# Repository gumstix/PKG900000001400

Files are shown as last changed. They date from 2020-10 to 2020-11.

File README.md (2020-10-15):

# Gumstix Raspberry Pi CM4 Development Board
## PKG900000001400 PKG900000001400

Designed by Gumstix in Geppetto, the **Gumstix Raspberry Pi CM4 Development Board** brings the best of the CM4 to light, from PCIe to Gigabit Ethernet to dual CSI2 cameras.  Whether you're building a NAS server or a face-detecting robot, The CM4 Development board has built-in features that will help your project along.  It provides the following connections for breaking out the features of the Raspberry Pi CM4:

* Raspberry Pi 4 Header
* USB-UART Console Port
* DSI connector for connecting to displays
* 2 x CSI2 connector for connecting a camera
* HDMI port for audio/display
* Gigabit Ethernet port
* USB Type-A port for expandability
* M.2 (M Key) with single lane PCIe, compatible with 2280 NVMe drives and Google Coral

The CM4 Development board is ideal for various applications, Including:
* Network attached mass storage (NAS)
* Media Centers
* Edge AI
* Smart home management

__Links:__
* [AutoDoc Datasheet][autodoc]
* [Specifications][spec]
* [Store Page][store]
* [Schematics and Layout][hardware]

[thumbnail]: https://d3iwea566ns1n1.cloudfront.net/images/product/1ae94bd9fed173c4b6867992084763ec15bd388f.png
[autodoc]: PKG900000001400_AutoDoc.pdf
[spec]: PKG900000001400_SpecSheet.pdf
[store]: https://store.gumstix.com/cm4-development-board/
[hardware]: hardware/hardware.md
[firmware]: firmware/firmware.md

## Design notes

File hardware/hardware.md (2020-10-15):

# Hardware

[Schematic PDF][pdf]
EAGLE [Schematic][sch] and [Layout][brd]

[pdf]: PKG900000001400.pdf
[brd]: PKG900000001400.brd
[sch]: PKG900000001400.sch

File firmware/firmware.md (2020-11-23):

# Firmware

__Custom Gumstix Ubuntu Server 20.04 images for Rasberry Pi CM4__:

* [Ubuntu Server 20.04](https://gumstix-ubuntu.s3-us-west-2.amazonaws.com/2020-10-18/raspberrypi-cm4/rosbuntu_cm4_i2.img.gz)
* Username: ubuntu
* Password: raspberry

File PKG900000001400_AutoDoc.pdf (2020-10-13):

# Gumstix Raspberry Pi CM4 Dev Board

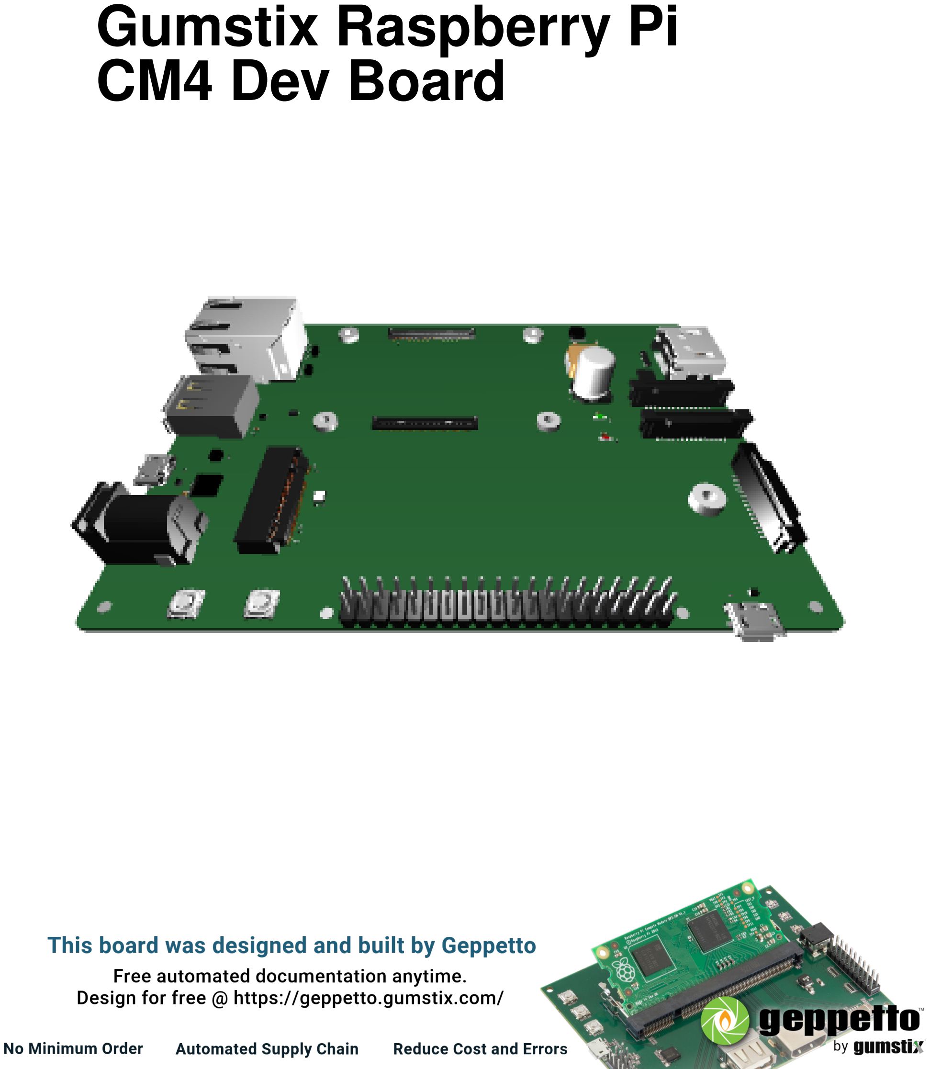
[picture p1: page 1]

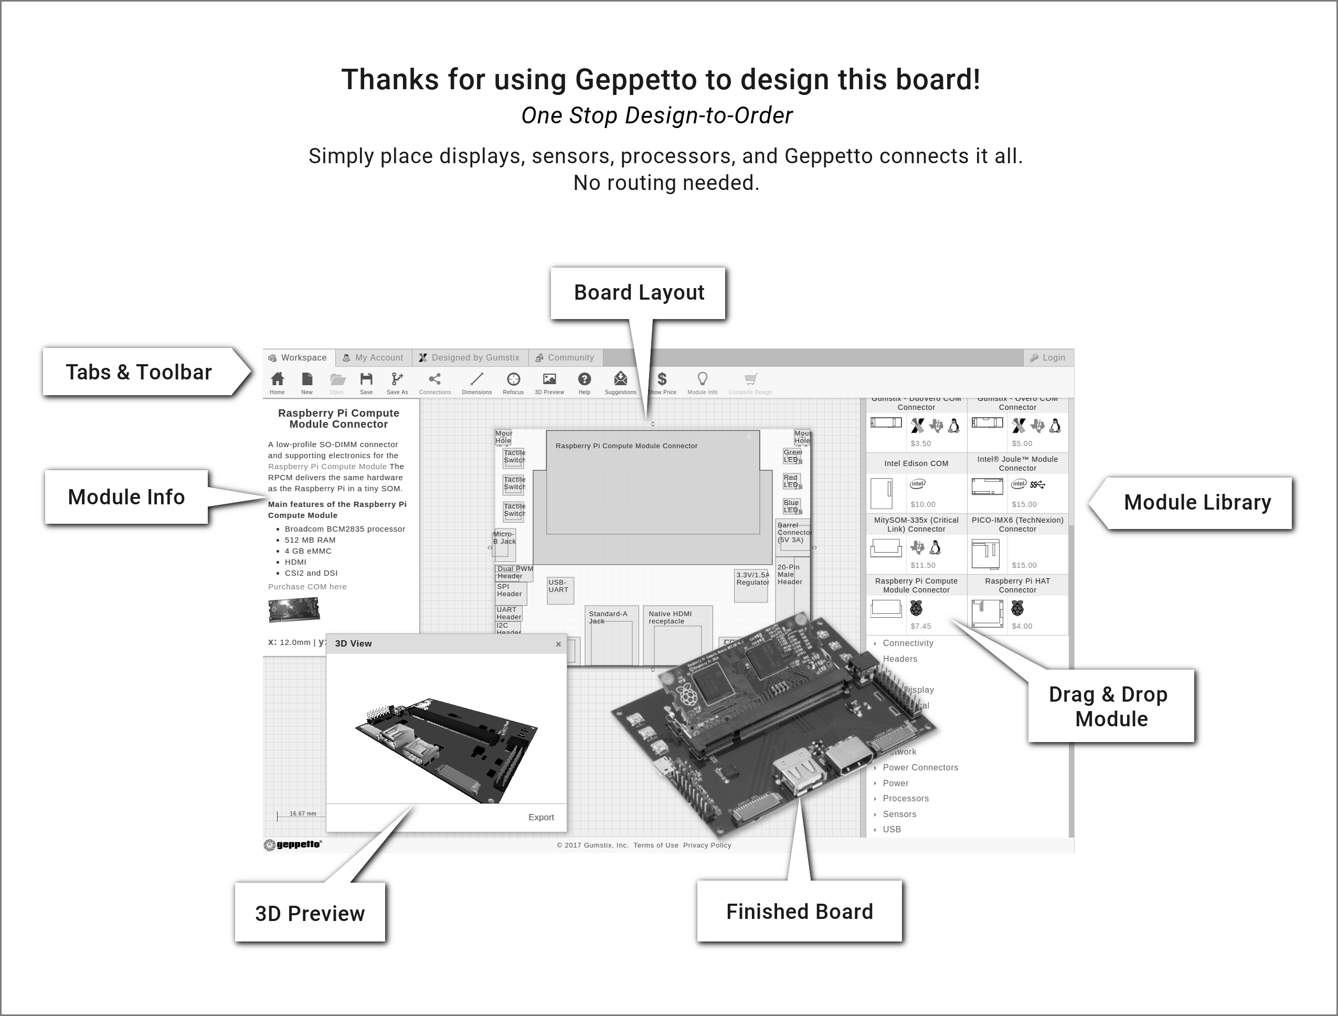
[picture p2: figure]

Gumstix, Inc. shall have no liability of any kind, express or implied, arising out of the use of the Information in this document, including direct, indirect, special or consequential damages.

Gumstix, Inc. may have patents, patent applications, trademarks, copyrights, trade secrets or other intellectual property rights pertaining to Gumstix products described in this document (collectively ”Gumstix Intellectual Property”).

Except as expressly provided in any written license or agreement from Gumstix, Inc., this document and the information contained therein does not create any license to Gumstix’s Intellectual Property.

The Information contained herein is subject to change without notice. Revisions may be issued regarding changes and/or additions.

Copyright

c 2020, Gumstix, Inc. All rights reserved.

## Board Description

Uses Raspberry Pi CM4 as its COM/processor.

Functional modules include:
USB-UART
USB Micro-B Jack
Camera Connector (CSI-2)
M.2 Key M Connector
Ethernet Connector

Powered by a Barrel Connector.

## Board Dimensions

12cm x 8.5cm

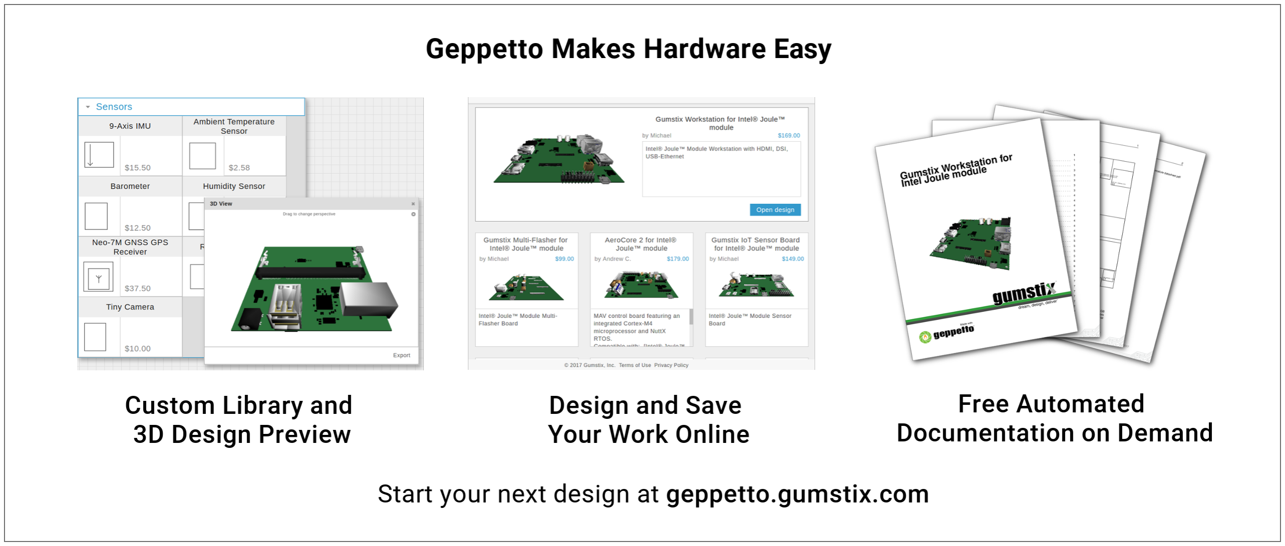
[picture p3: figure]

i

## Contents

1 Modules on Board | 1

ii

Gumstix Raspberry Pi CM4 Dev Board | iii
2 Module Connections Graph | 9
3 Module Power Graph | 10

Revised July 20, 2020

Gumstix Raspberry Pi CM4 Dev Board | 1

## 1 Modules on Board

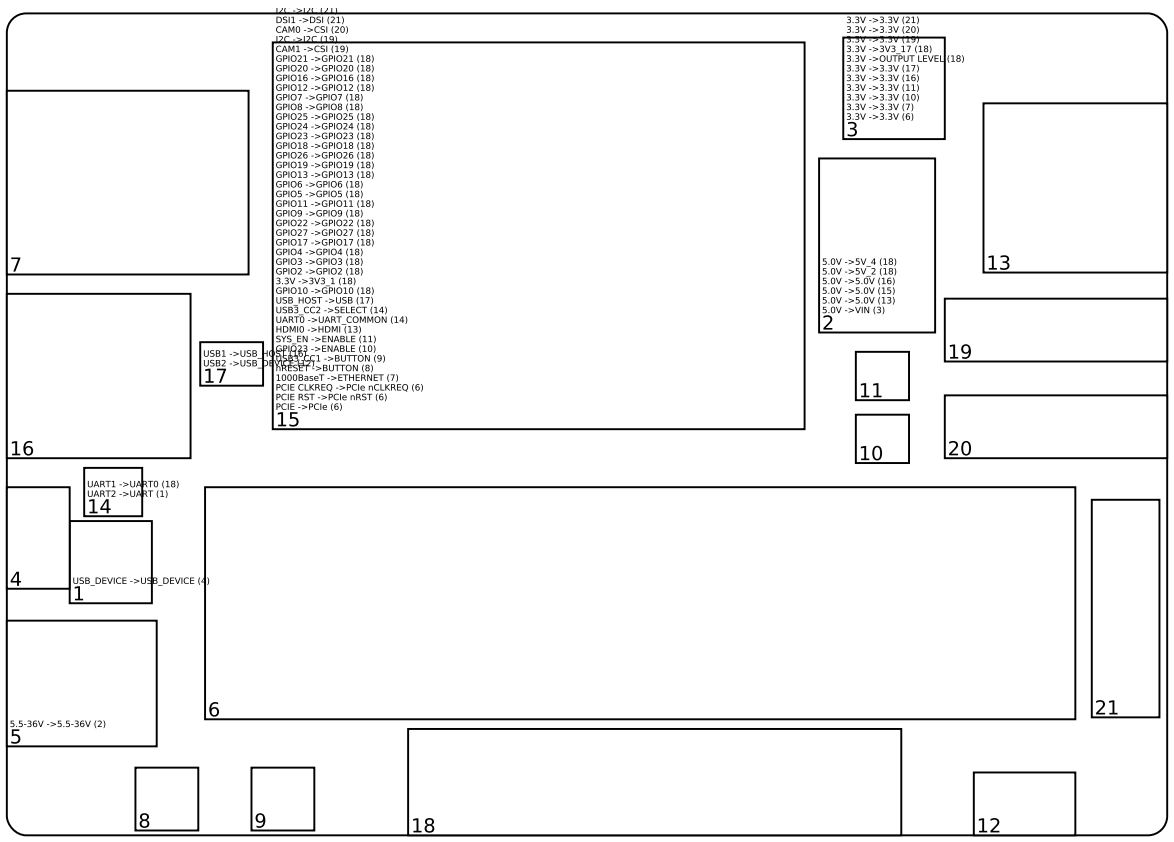
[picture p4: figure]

### 1.1 Converters

### 1.1.1 USB-UART (v21) (1)

Also known as an FTDI, this USB to UART converter allows a USB connection to the board to be-have as a virtual RS232 serial connection. It offers direct and complete access to the system from a development machine by way of the FTDI FT232RQ USB – UART IC.

Technical documentation for the FT232RQ is available at:

http://www.ftdichip.com/Support/Documents/DataSheets/ICs/DS_FT232R.pdf

This USB to UART converter connects a host machine from Micro-B Jack (4) to UART2 on UART Mux (2 output) (14).

### 1.2 Power

1.2.1 5V/5A Regulator (v16) (2)

Takes 5.5 - 36V input from Barrel Connector (2.1mm x 5.5mm) (5) and provides up to 5A at 5V to:

- 3.3V/1.5A Regulator (3)
- HDMI (13)
- Raspberry Pi CM4 Connector (15)
- USB Standard-A Jack (16)
- Raspberry Pi 4 Header (18)
- Raspberry Pi 4 Header (18)

1.2.2 3.3V/1.5A Regulator (v21) (3)

This DC to DC step down regulator provides a 3.3V DC output at 1.5A needed by certain components on this board. It is capable of accepting an input voltage between 3.1 to 16V DC and output is controlled by the TI TPS6211 buck regulator.
It recieves VIN from 5V/5A Regulator (2).

The datasheet for the TPS6211 regulator is available at:

http://www.ti.com/lit/ds/symlink/tps62110.pdf

This regulator provides 3.3V to:

- M.2 Key M Connector (6)
- Ethernet Connector (7)
- Top-side LED (10)
- Top-side LED (11)
- USB Standard-A Jack (16)
- USB 2-Port Switch (17)
- Raspberry Pi 4 Header (18)
- Raspberry Pi 4 Header (18)
- Raspberry Pi Vertical Camera Connector (19)
- Raspberry Pi Vertical Camera Connector (20)
- Raspberry Pi Vertical Display Connector (21)

### 1.3 USB

### 1.3.1 Micro-B Jack (v20) (4)

The USB micro-B port module allows your design to connect as a USB device to a USB host.

This module is connected to USB DEVICE on USB-UART (1).

This module does not supply power.

### 1.3.2 Micro-B Jack (v20) (12)

The USB micro-B port module allows your design to connect as a USB device to a USB host.

This module is connected to USB2 on USB 2-Port Switch (17).

This module does not supply power.

### 1.3.3 USB Standard-A Jack (v19) (16)

A standard A USB host port that allows you to connect USB devices to the board. This port is connected to USB1 on USB 2-Port Switch (17).

### 1.3.4 USB 2-Port Switch (v1) (17)

USB 2-Port Switch allows the sharing of a single USB 2.0 port.

It requires:

- 3.3V from 3.3V/1.5A Regulator (3)
- USB from Raspberry Pi CM4 Connector (15)

It provides the following outputs:

- USB2 to Micro-B Jack (12)
- USB1 to USB Standard-A Jack (16)

### 1.4 Power Connectors

### 1.4.1 Barrel Connector (2.1mm x 5.5mm) (v8) (5)

Standard 2.1mm x 5.1mm barrel connector.

This power jack provides up to 36V to the following modules:

- 5V/5A Regulator (2)

### 1.5 Connectors (Signal)

### 1.5.1 M.2 Key M Connector (v7) (6)

The M.2 Key M expansion slot includes interface options for PCIe (x1, X2, or X4) for SSD’s.

The M.2 Key M Connector module receives the following inputs:

- 3.3V from 3.3V/1.5A Regulator (3)
- PCIe from Raspberry Pi CM4 Connector (15)

- PCIe nRST from Raspberry Pi CM4 Connector (15)
- PCIe nCLKREQ from Raspberry Pi CM4 Connector (15)

### 1.5.2 UART Mux (2 output) (v10) (14)

A bidirectional 2 x SPDT switch connects two UART interfaces (RX/TX only). A SELECT line is used to control which UART is output.

This UART 2-output mux switches between UART0 on Raspberry Pi 4 Header (18) or UART on USB-UART (1) to UART0 on Raspberry Pi CM4 Connector (15).

The output is controlled by USB3 CC2 on Raspberry Pi CM4 Connector (15).

### 1.5.3 Raspberry Pi Vertical Camera Connector (v6) (19) — CAM1

The Raspberry Pi Vertical camera connector module is a 15-pin ribbon connector that exposes a 2-lane MIPI camera system to an external high-resolution camera module.

The CSI port is connected to CAM1 on Raspberry Pi CM4 Connector (15).

I2C communication is connected to I2C on Raspberry Pi CM4 Connector (15).

ENABLE input provided by GPIO CAMERA on Raspberry Pi CM4 Connector (15).

### 1.5.4 Raspberry Pi Vertical Camera Connector (v6) (20) — CAM0

The Raspberry Pi Vertical camera connector module is a 15-pin ribbon connector that exposes a 2-lane MIPI camera system to an external high-resolution camera module.

The CSI port is connected to CAM0 on Raspberry Pi CM4 Connector (15).

I2C communication is connected to I2C ID on Raspberry Pi CM4 Connector (15).

ENABLE input provided by GPIO CAMERA on Raspberry Pi CM4 Connector (15).

### 1.5.5 Raspberry Pi Vertical Display Connector (v1) (21)

The DSI connector module is a 15-pin ribbon connector that exposes a 2-lane MIPI DSI display bus to an external LCD display.

The DSI port is connected to DSI1 on Raspberry Pi CM4 Connector (15)

I2C communication is connected to I2C on Raspberry Pi CM4 Connector (15) .

### 1.6 Network and Wireless

### 1.6.1 Ethernet Connector (v5) (7)

This module offers a 10/100 Base-T or 1000 Base-T Ethernet connection.

The module provides ethernet to

1000BaseT on Raspberry Pi CM4 Connector (15)

### 1.7 Lights and Switches

### 1.7.1 Tactile Switch (v22) (8)

This 4.9 sq. mm pull-down touch switch provides a user input for the signal nRESET on Raspberry Pi CM4 Connector (15).

### 1.7.2 Tactile Switch (v22) (9)

This 4.9 sq. mm pull-down touch switch provides a user input for the signal USB3 CC1 on Raspberry Pi CM4 Connector (15).

### 1.7.3 Top-side LED (v12) (10)

The top-side LED module contains a 1608 standard size LED of a user-selected color, mounted on the top side of a Geppetto board.

The LED is active-high on GPIO23 from Raspberry Pi CM4 Connector (15).

### 1.7.4 Top-side LED (v12) (11)

The top-side LED module contains a 1608 standard size LED of a user-selected color, mounted on the top side of a Geppetto board.

The LED is active-high on SYS EN from Raspberry Pi CM4 Connector (15).

### 1.8 Monitors

### 1.8.1 HDMI (v22) (13)

The native HDMI receptacle module provides HDMI video and audio signals to an external display and speakers. This module uses the TI TPD12S016UFQN HDMI companion chip with a standard HDMI port to provide ESD-protected display connectivity.

The datasheet for the TPD12S016 IC can be found at:

http://www.ti.com/lit/ds/symlink/tpd12s016.pdf

The module transmits high definition video from HDMI0 on Raspberry Pi CM4 Connector (15) .

### 1.9 COM Connectors

### 1.9.1 Raspberry Pi CM4 Connector (v2) (15)

The Raspberry Pi Compute Module 4 (RPCM4) module contains two connectors to interface with the RPCM4 device. The RPCM4 COM connector is ONLY compatible with the RPCM4.

Technical details for the RPCM modules can be found at:

https://www.raspberrypi.org/documentation/hardware/computemodule/datasheet.md

It requires:

- 5.0V from 5V/5A Regulator (2)

The Geppetto Pi Compute 4 connector provides the following outputs:

- PCIE to M.2 Key M Connector (6)
- PCIE RST to M.2 Key M Connector (6)
- PCIE CLKREQ to M.2 Key M Connector (6)
- 1000BaseT to Ethernet Connector (7)
- nRESET to Tactile Switch (8)
- USB3 CC1 to Tactile Switch (9)
- GPIO23 to:

– Top-side LED (10)
– Raspberry Pi 4 Header (18)
- SYS EN to Top-side LED (11)
- HDMI0 to HDMI (13)
- UART0 to UART Mux (2 output) (14)
- USB3 CC2 to UART Mux (2 output) (14)
- USB HOST to USB 2-Port Switch (17)
- GPIO10 to Raspberry Pi 4 Header (18)
- 3.3V to Raspberry Pi 4 Header (18)
- GPIO2 to Raspberry Pi 4 Header (18)
- GPIO3 to Raspberry Pi 4 Header (18)
- GPIO4 to Raspberry Pi 4 Header (18)
- GPIO17 to Raspberry Pi 4 Header (18)
- GPIO27 to Raspberry Pi 4 Header (18)
- GPIO22 to Raspberry Pi 4 Header (18)
- GPIO9 to Raspberry Pi 4 Header (18)

- GPIO11 to Raspberry Pi 4 Header (18)
- GPIO5 to Raspberry Pi 4 Header (18)
- GPIO6 to Raspberry Pi 4 Header (18)
- GPIO13 to Raspberry Pi 4 Header (18)
- GPIO19 to Raspberry Pi 4 Header (18)
- GPIO26 to Raspberry Pi 4 Header (18)
- GPIO18 to Raspberry Pi 4 Header (18)
- GPIO24 to Raspberry Pi 4 Header (18)
- GPIO25 to Raspberry Pi 4 Header (18)
- GPIO8 to Raspberry Pi 4 Header (18)
- GPIO7 to Raspberry Pi 4 Header (18)
- GPIO12 to Raspberry Pi 4 Header (18)
- GPIO16 to Raspberry Pi 4 Header (18)
- GPIO20 to Raspberry Pi 4 Header (18)
- GPIO21 to Raspberry Pi 4 Header (18)
- CAM1 to Raspberry Pi Vertical Camera Connector (19)
- I2C to:

– Raspberry Pi Vertical Camera Connector (19)

– Raspberry Pi Vertical Display Connector (21)

- CAM0 to Raspberry Pi Vertical Camera Connector (20)
- DSI1 to Raspberry Pi Vertical Display Connector (21)
- GPIO CAMERA to:

– Raspberry Pi Vertical Camera Connector (20)

– Raspberry Pi Vertical Camera Connector (19)

- I2C ID to Raspberry Pi Vertical Camera Connector (20)

### 1.10 Custom Modules

### 1.10.1 Raspberry Pi 4 Header (v5) (18)

The 40-pin header module offers up to 40 pins that can be used at the customer’s discretion.

This module has the following connections:

- 5V 2 to 5.0V from 5V/5A Regulator (2)
- 5V 4 to 5.0V from 5V/5A Regulator (2)

- OUTPUT LEVEL to 3.3V from 3.3V/1.5A Regulator (3)
- 3V3 17 to 3.3V from 3.3V/1.5A Regulator (3)
- UART0 to UART1 from UART Mux (2 output) (14)
- GPIO10 to GPIO10 from Raspberry Pi CM4 Connector (15)
- 3V3 1 to 3.3V from Raspberry Pi CM4 Connector (15)
- GPIO2 to GPIO2 from Raspberry Pi CM4 Connector (15)
- GPIO3 to GPIO3 from Raspberry Pi CM4 Connector (15)
- GPIO4 to GPIO4 from Raspberry Pi CM4 Connector (15)
- GPIO17 to GPIO17 from Raspberry Pi CM4 Connector (15)
- GPIO27 to GPIO27 from Raspberry Pi CM4 Connector (15)
- GPIO22 to GPIO22 from Raspberry Pi CM4 Connector (15)
- GPIO9 to GPIO9 from Raspberry Pi CM4 Connector (15)
- GPIO11 to GPIO11 from Raspberry Pi CM4 Connector (15)
- GPIO5 to GPIO5 from Raspberry Pi CM4 Connector (15)
- GPIO6 to GPIO6 from Raspberry Pi CM4 Connector (15)
- GPIO13 to GPIO13 from Raspberry Pi CM4 Connector (15)
- GPIO19 to GPIO19 from Raspberry Pi CM4 Connector (15)
- GPIO26 to GPIO26 from Raspberry Pi CM4 Connector (15)
- GPIO18 to GPIO18 from Raspberry Pi CM4 Connector (15)
- GPIO23 to GPIO23 from Raspberry Pi CM4 Connector (15)
- GPIO24 to GPIO24 from Raspberry Pi CM4 Connector (15)
- GPIO25 to GPIO25 from Raspberry Pi CM4 Connector (15)
- GPIO8 to GPIO8 from Raspberry Pi CM4 Connector (15)
- GPIO7 to GPIO7 from Raspberry Pi CM4 Connector (15)
- GPIO12 to GPIO12 from Raspberry Pi CM4 Connector (15)
- GPIO16 to GPIO16 from Raspberry Pi CM4 Connector (15)
- GPIO20 to GPIO20 from Raspberry Pi CM4 Connector (15)
- GPIO21 to GPIO21 from Raspberry Pi CM4 Connector (15)

## 2 Module Connections Graph

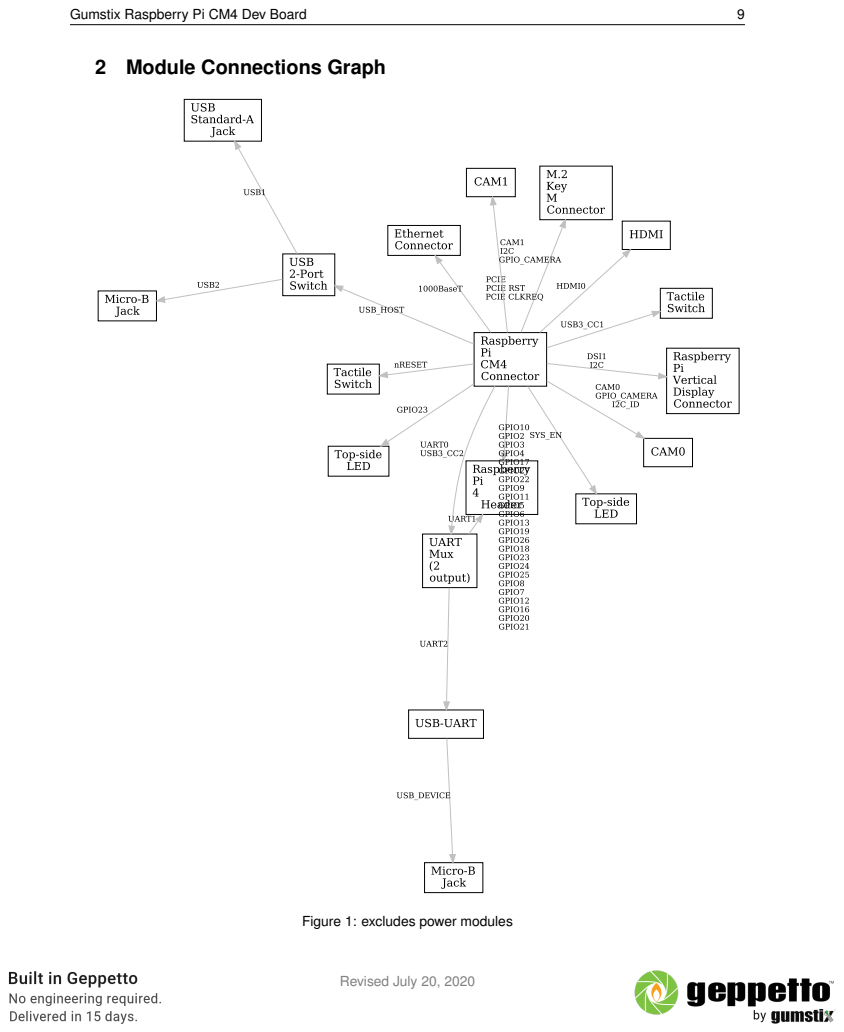
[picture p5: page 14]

Figure 1: excludes power modules

## 3 Module Power Graph

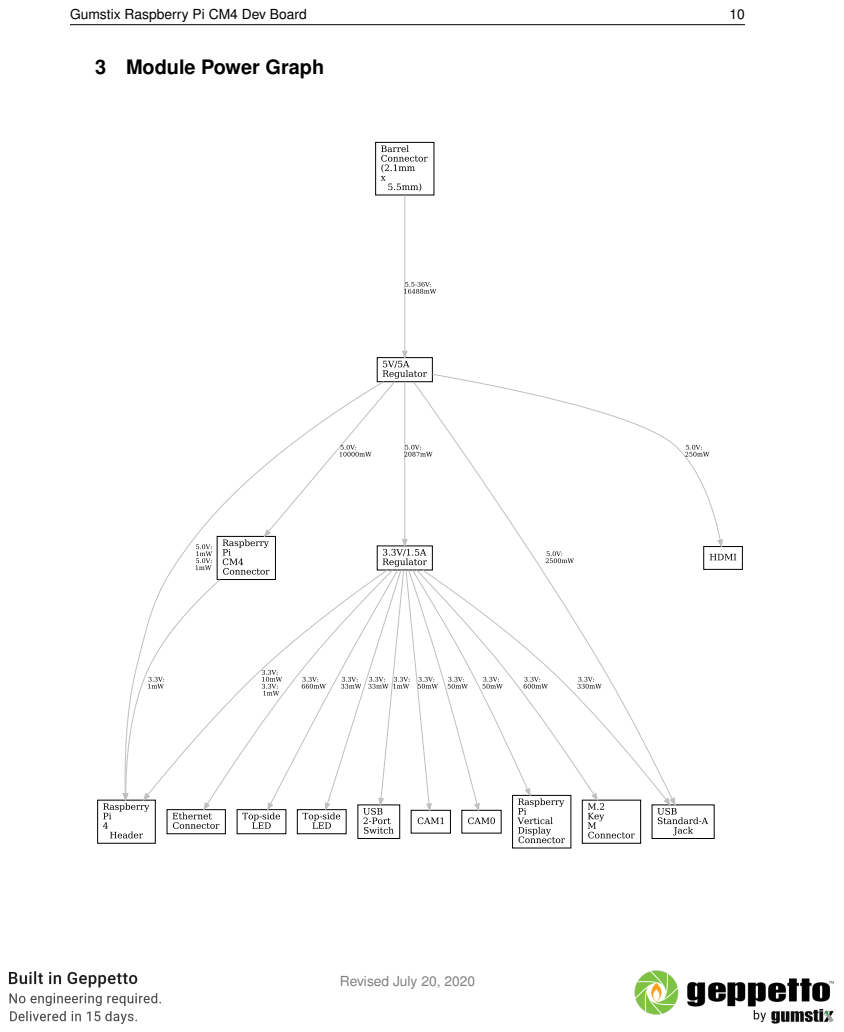
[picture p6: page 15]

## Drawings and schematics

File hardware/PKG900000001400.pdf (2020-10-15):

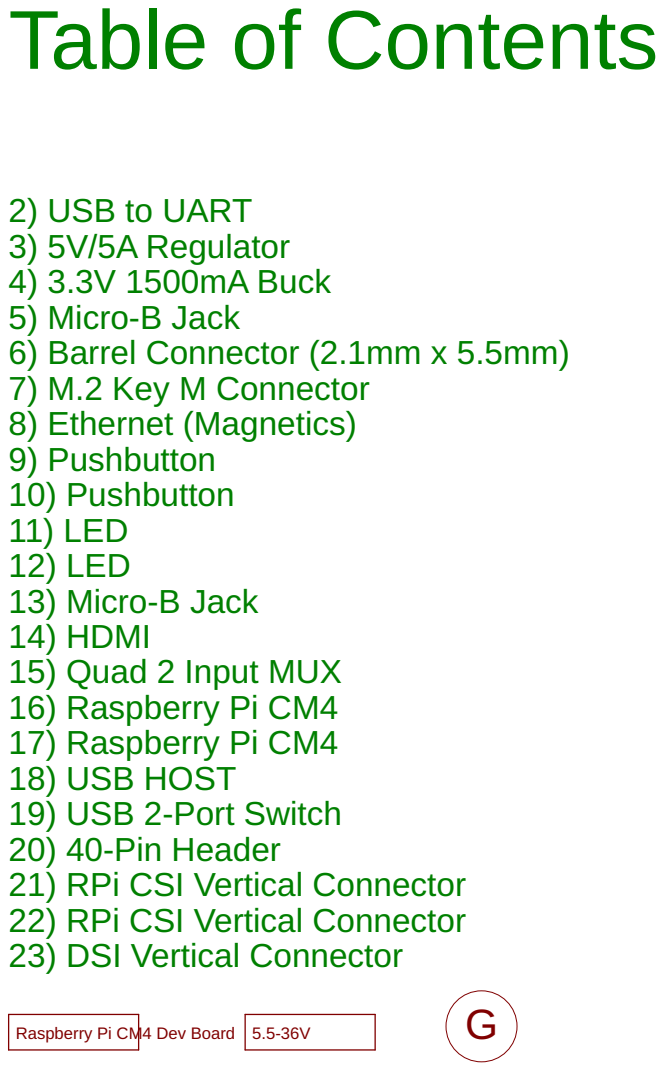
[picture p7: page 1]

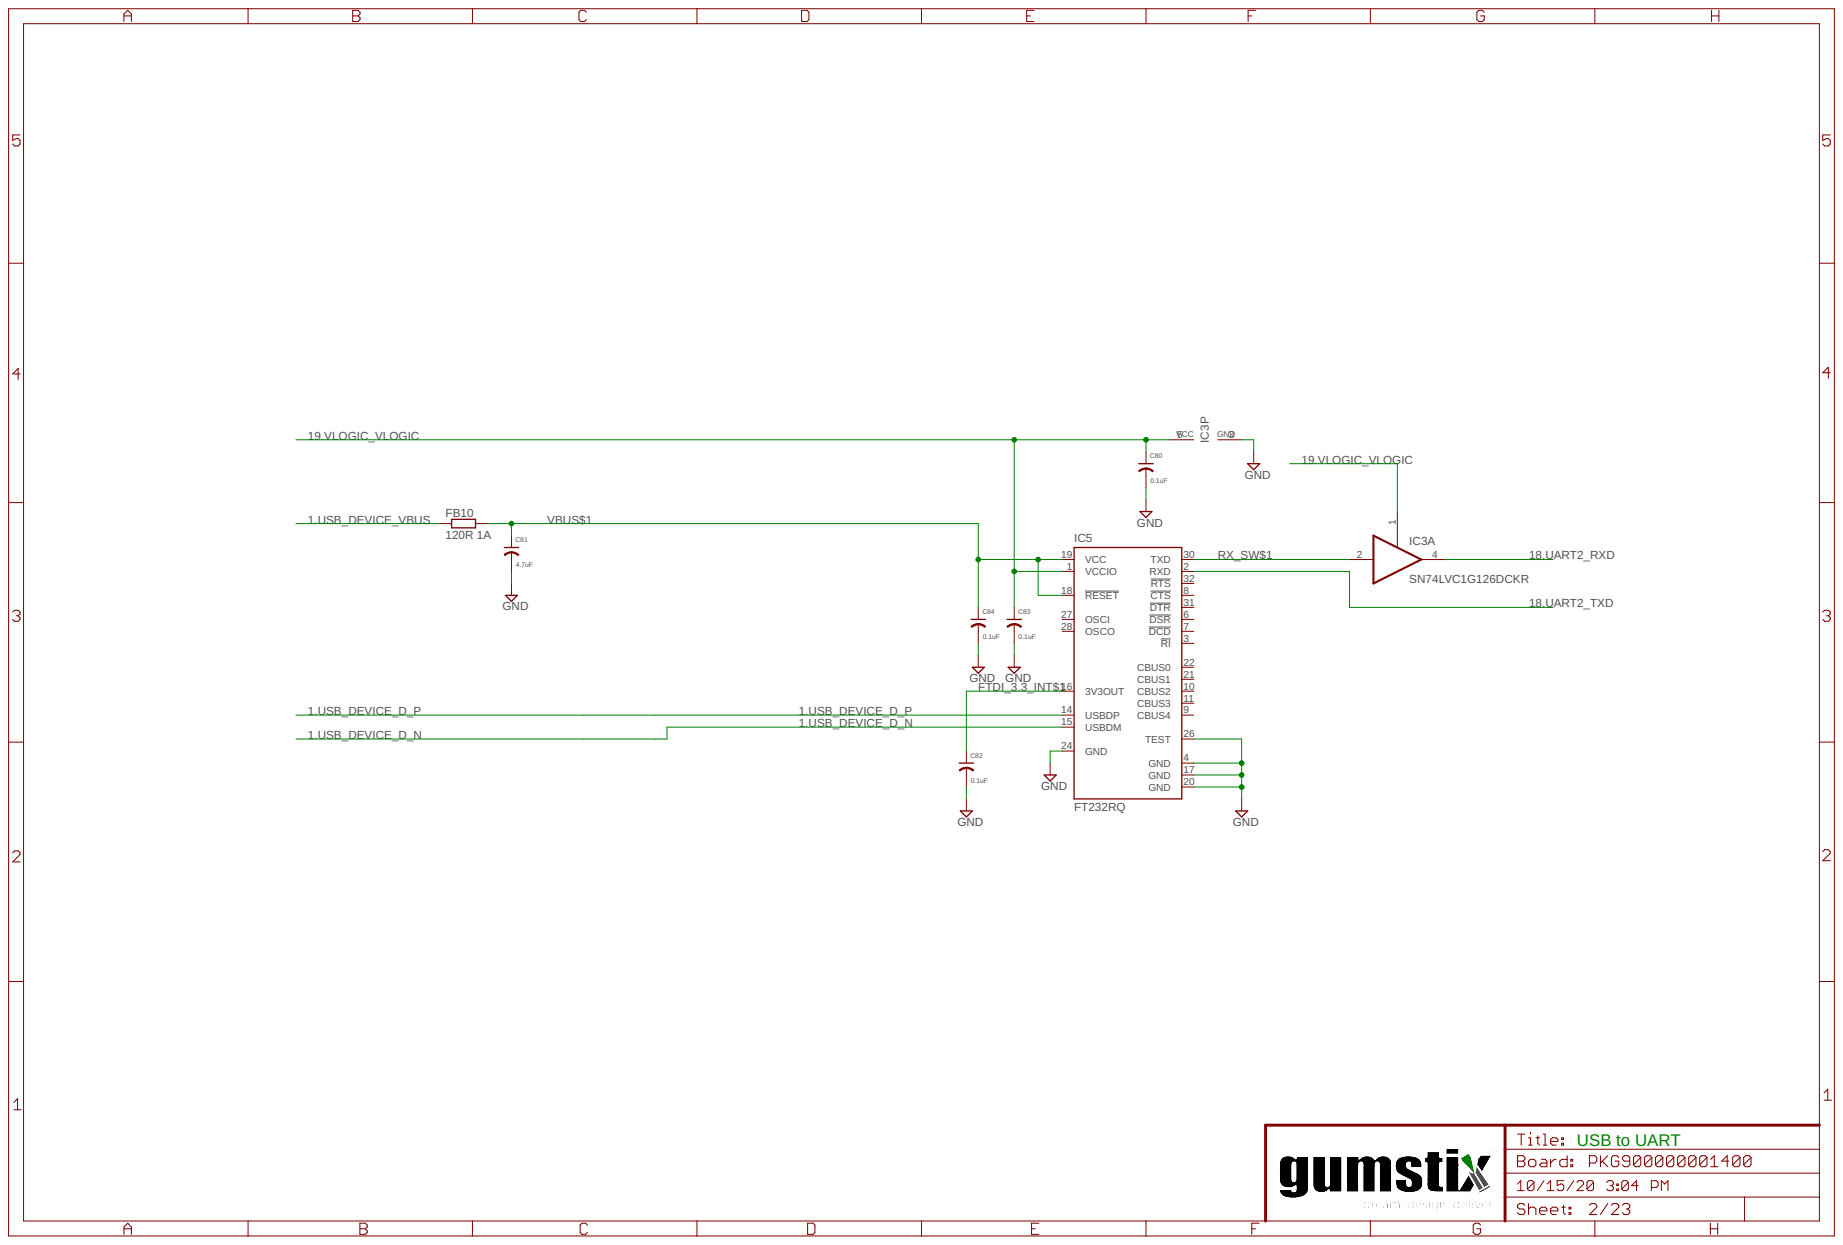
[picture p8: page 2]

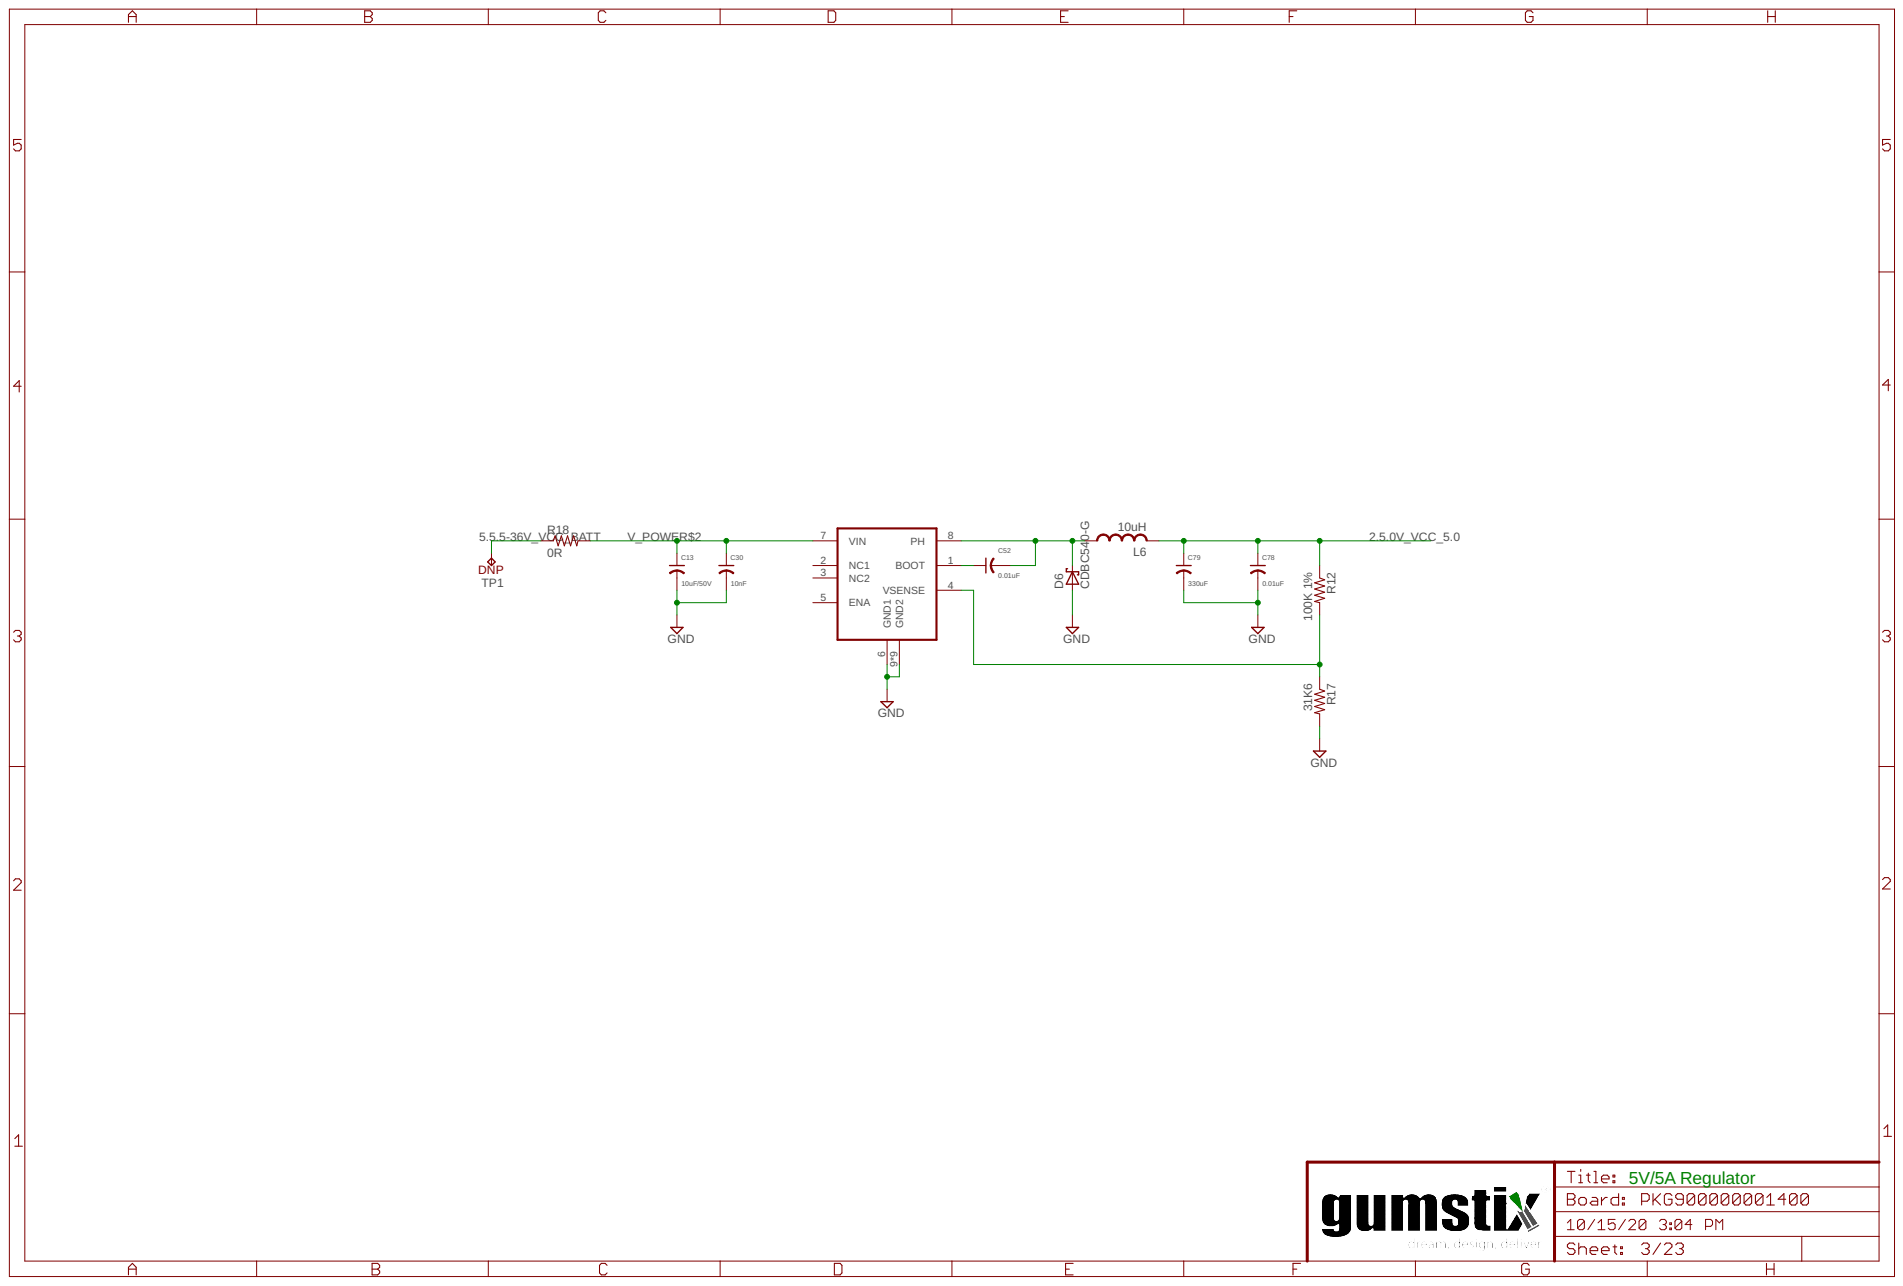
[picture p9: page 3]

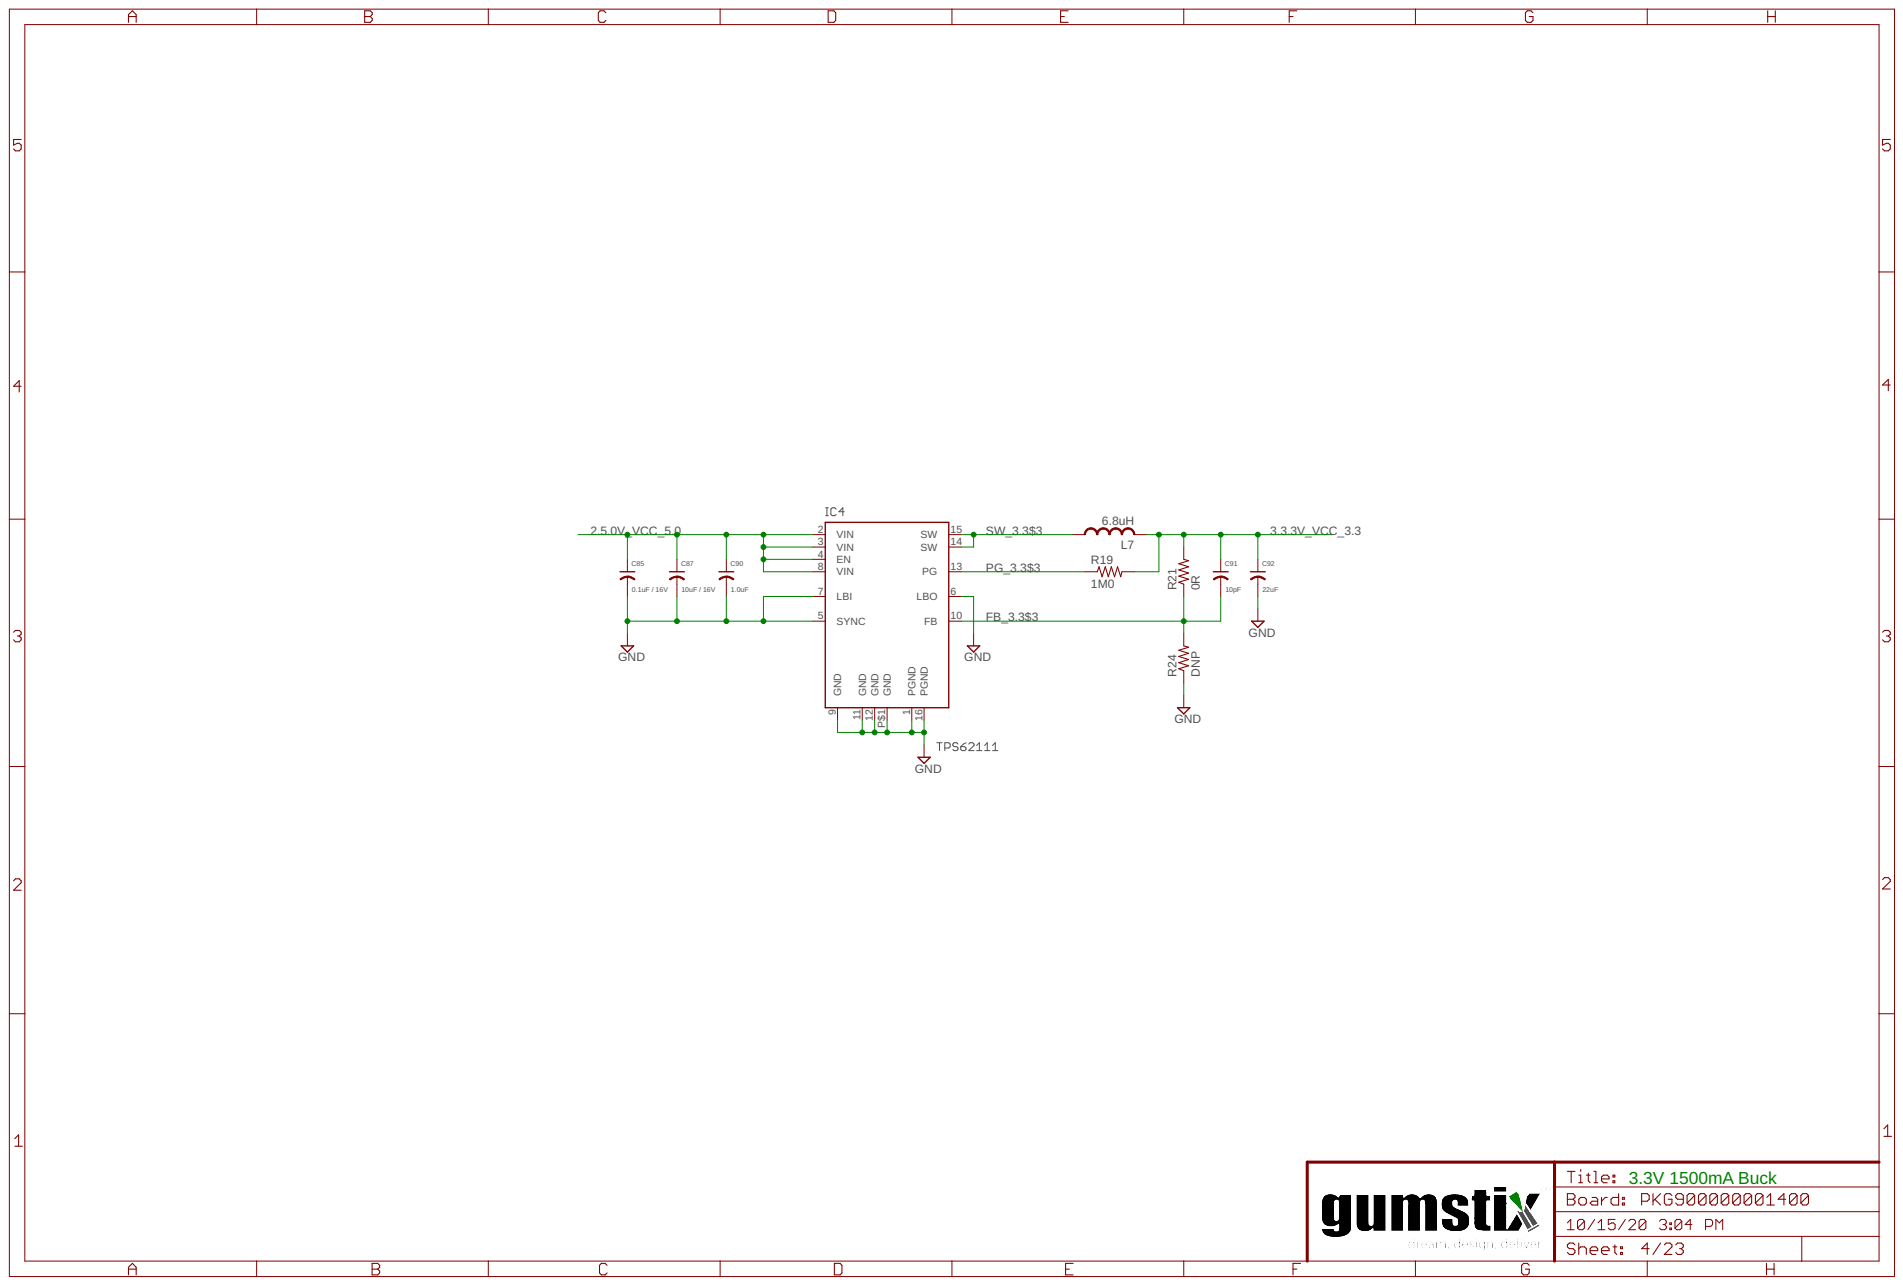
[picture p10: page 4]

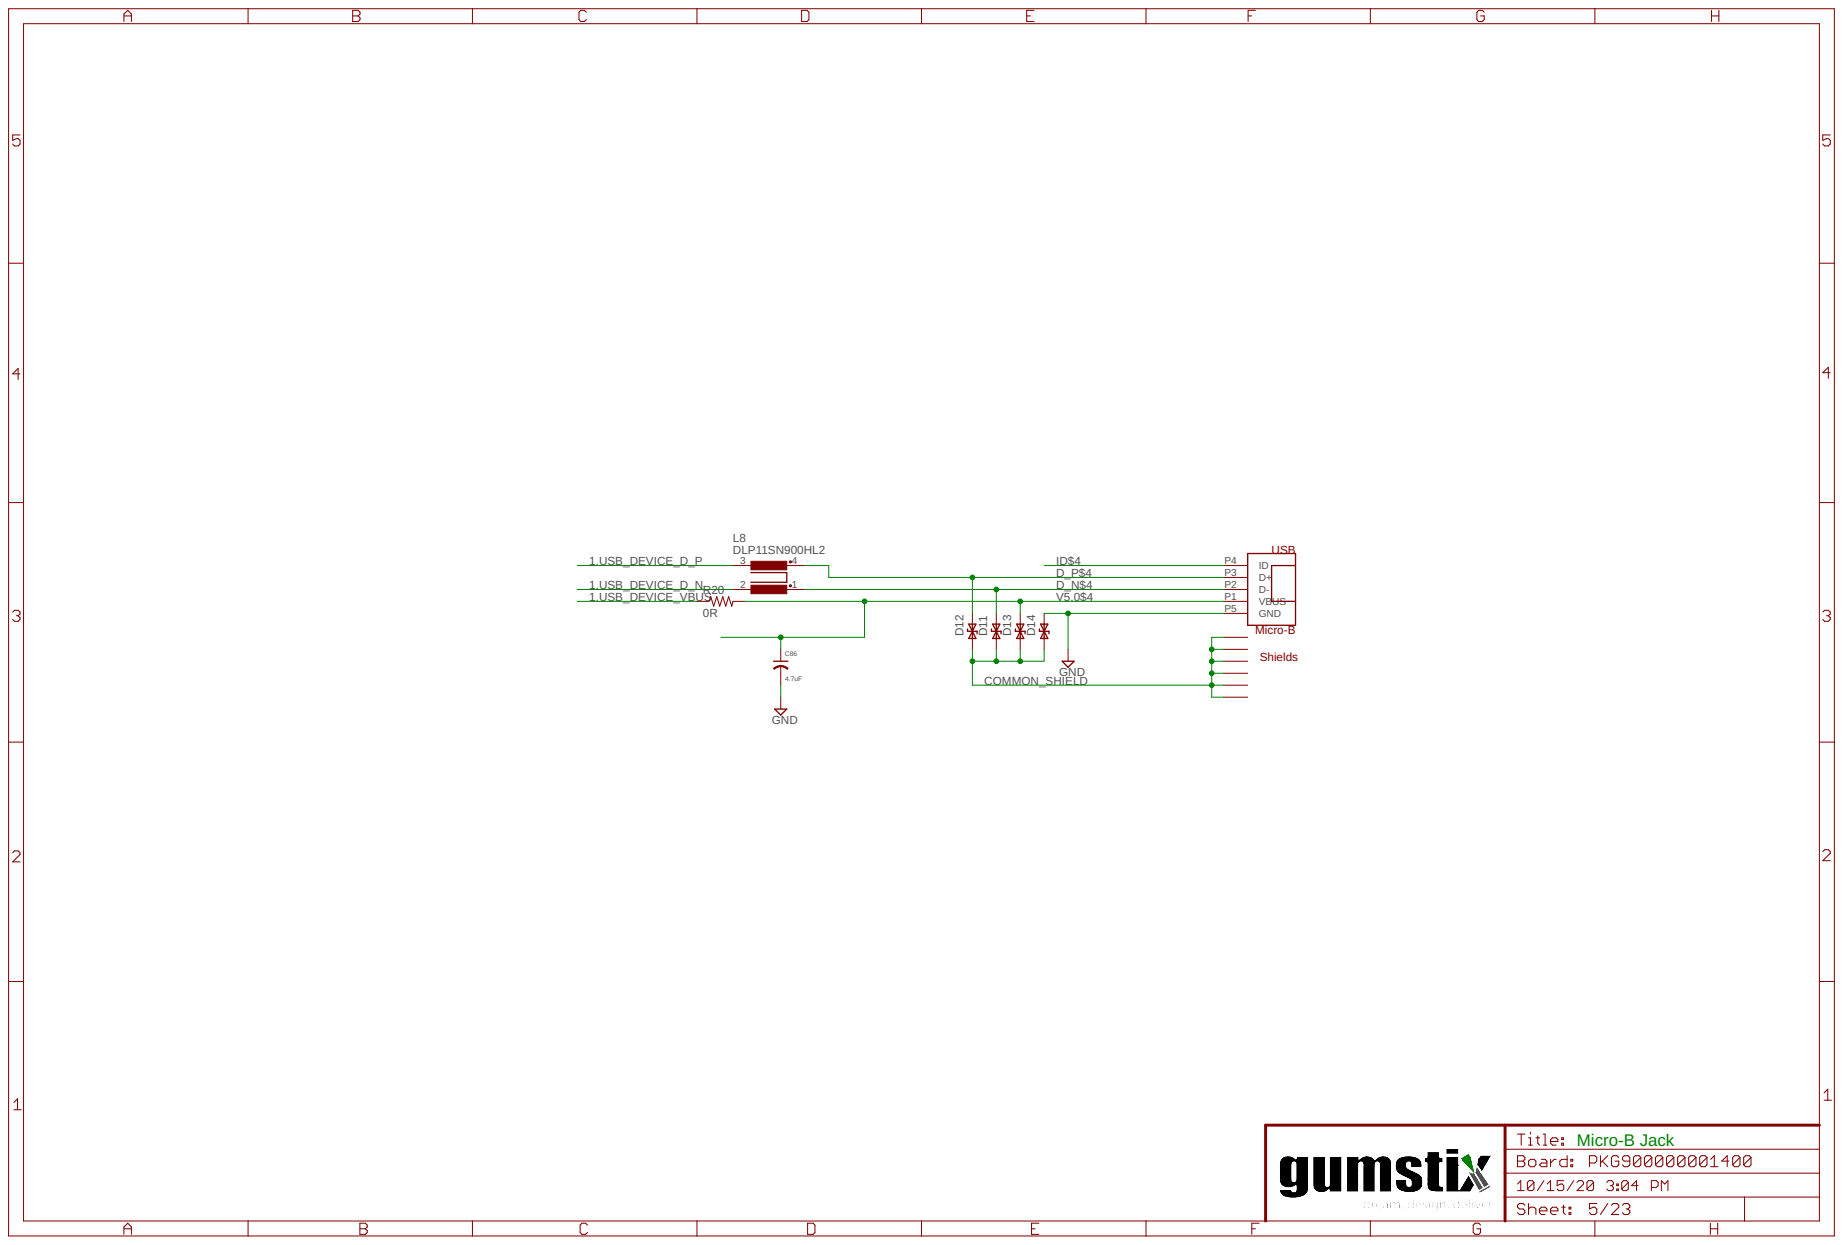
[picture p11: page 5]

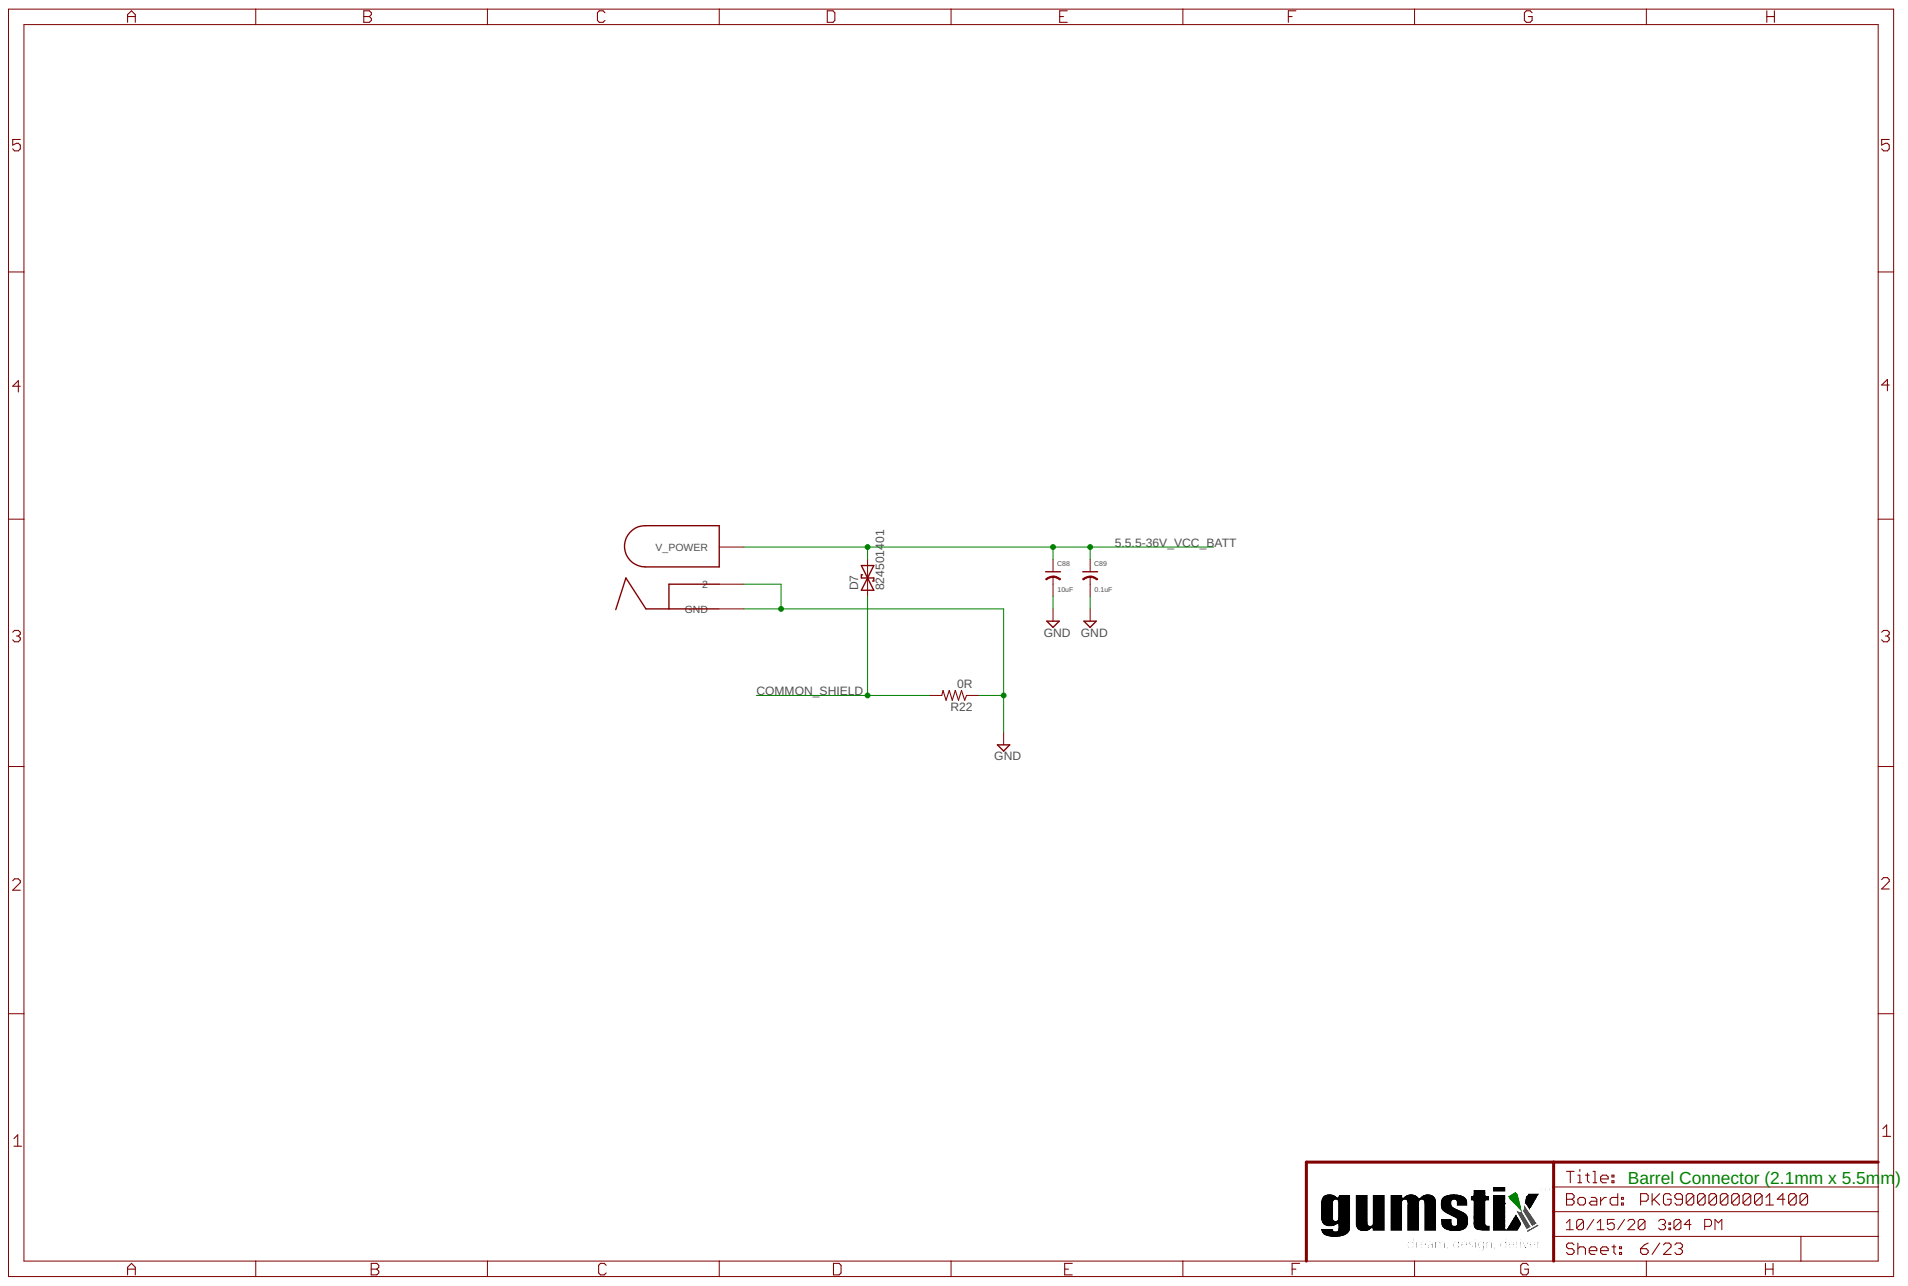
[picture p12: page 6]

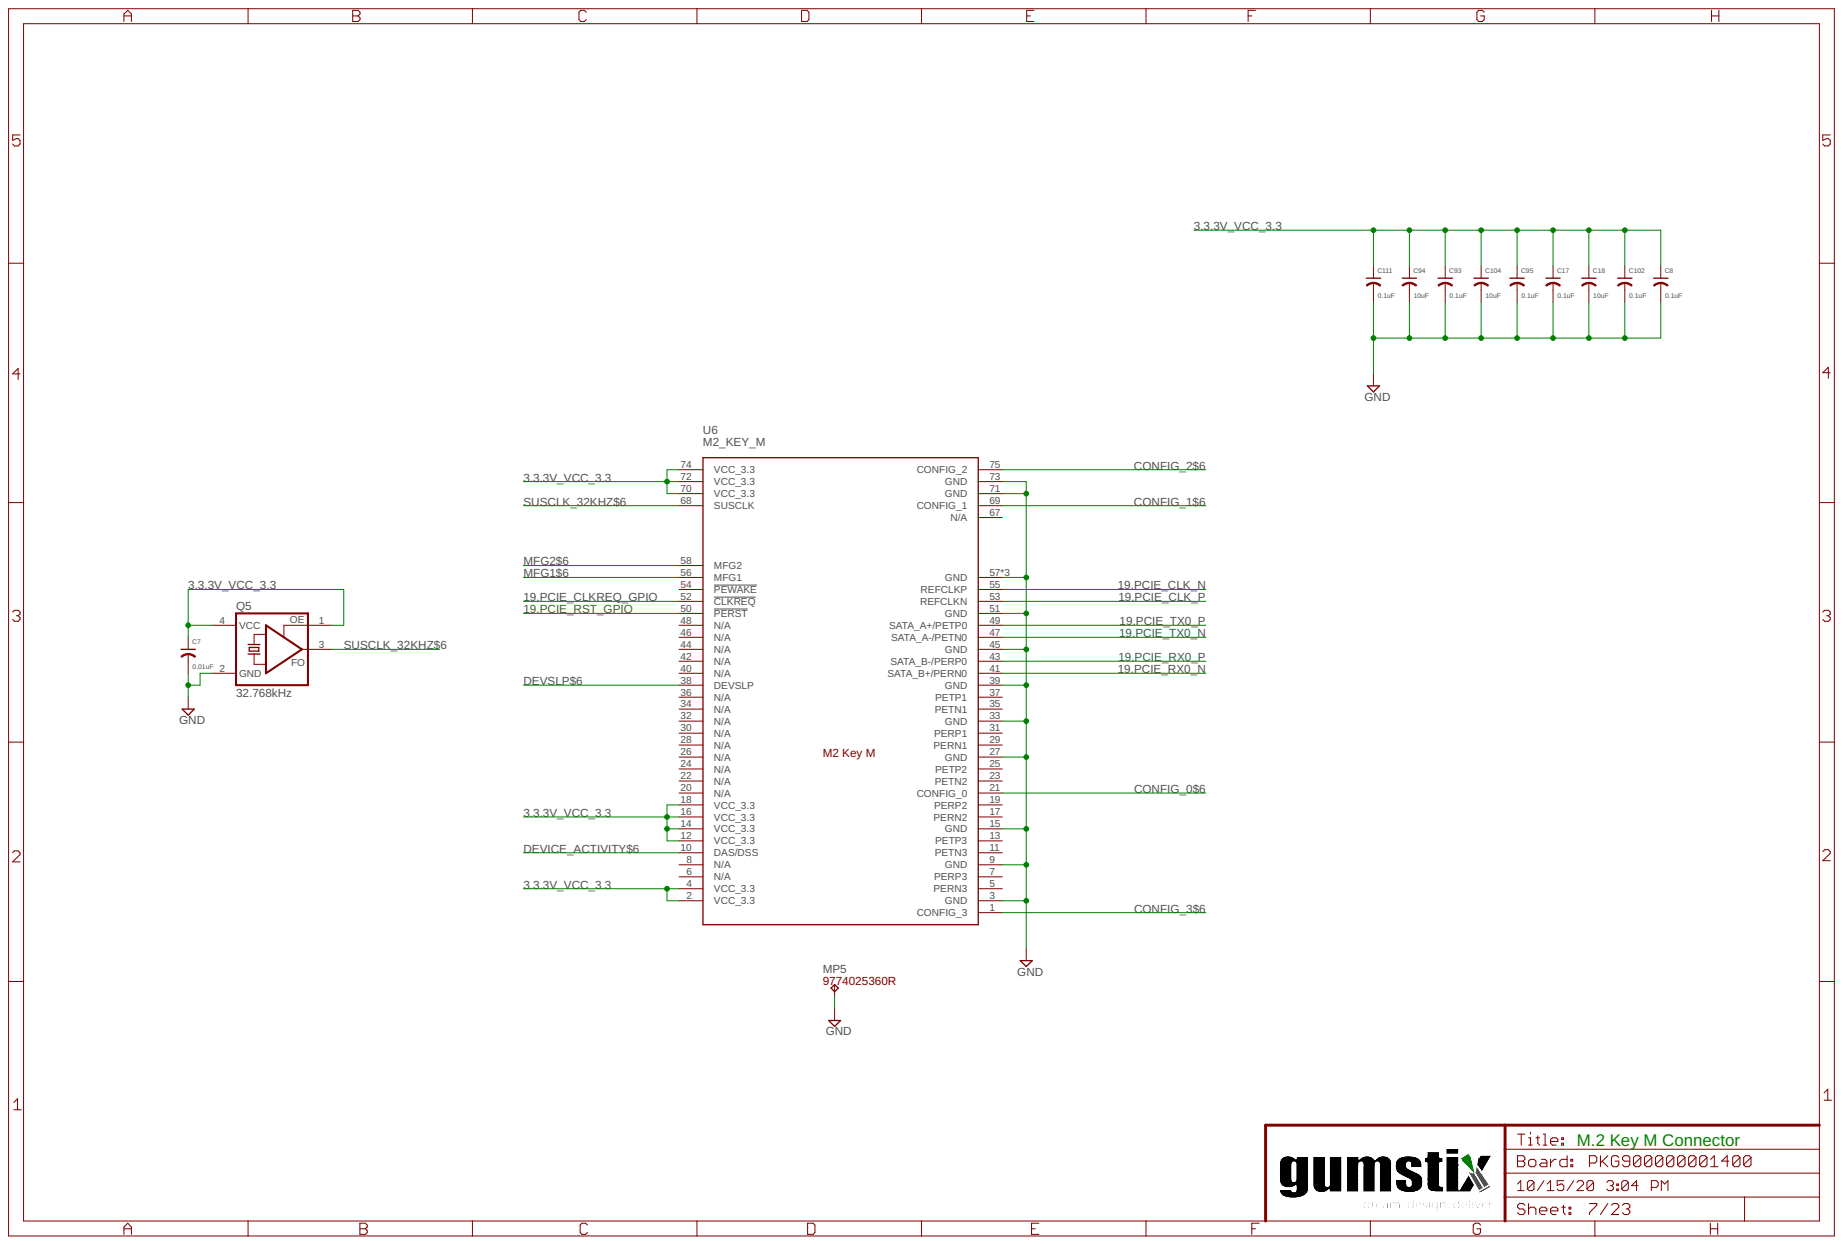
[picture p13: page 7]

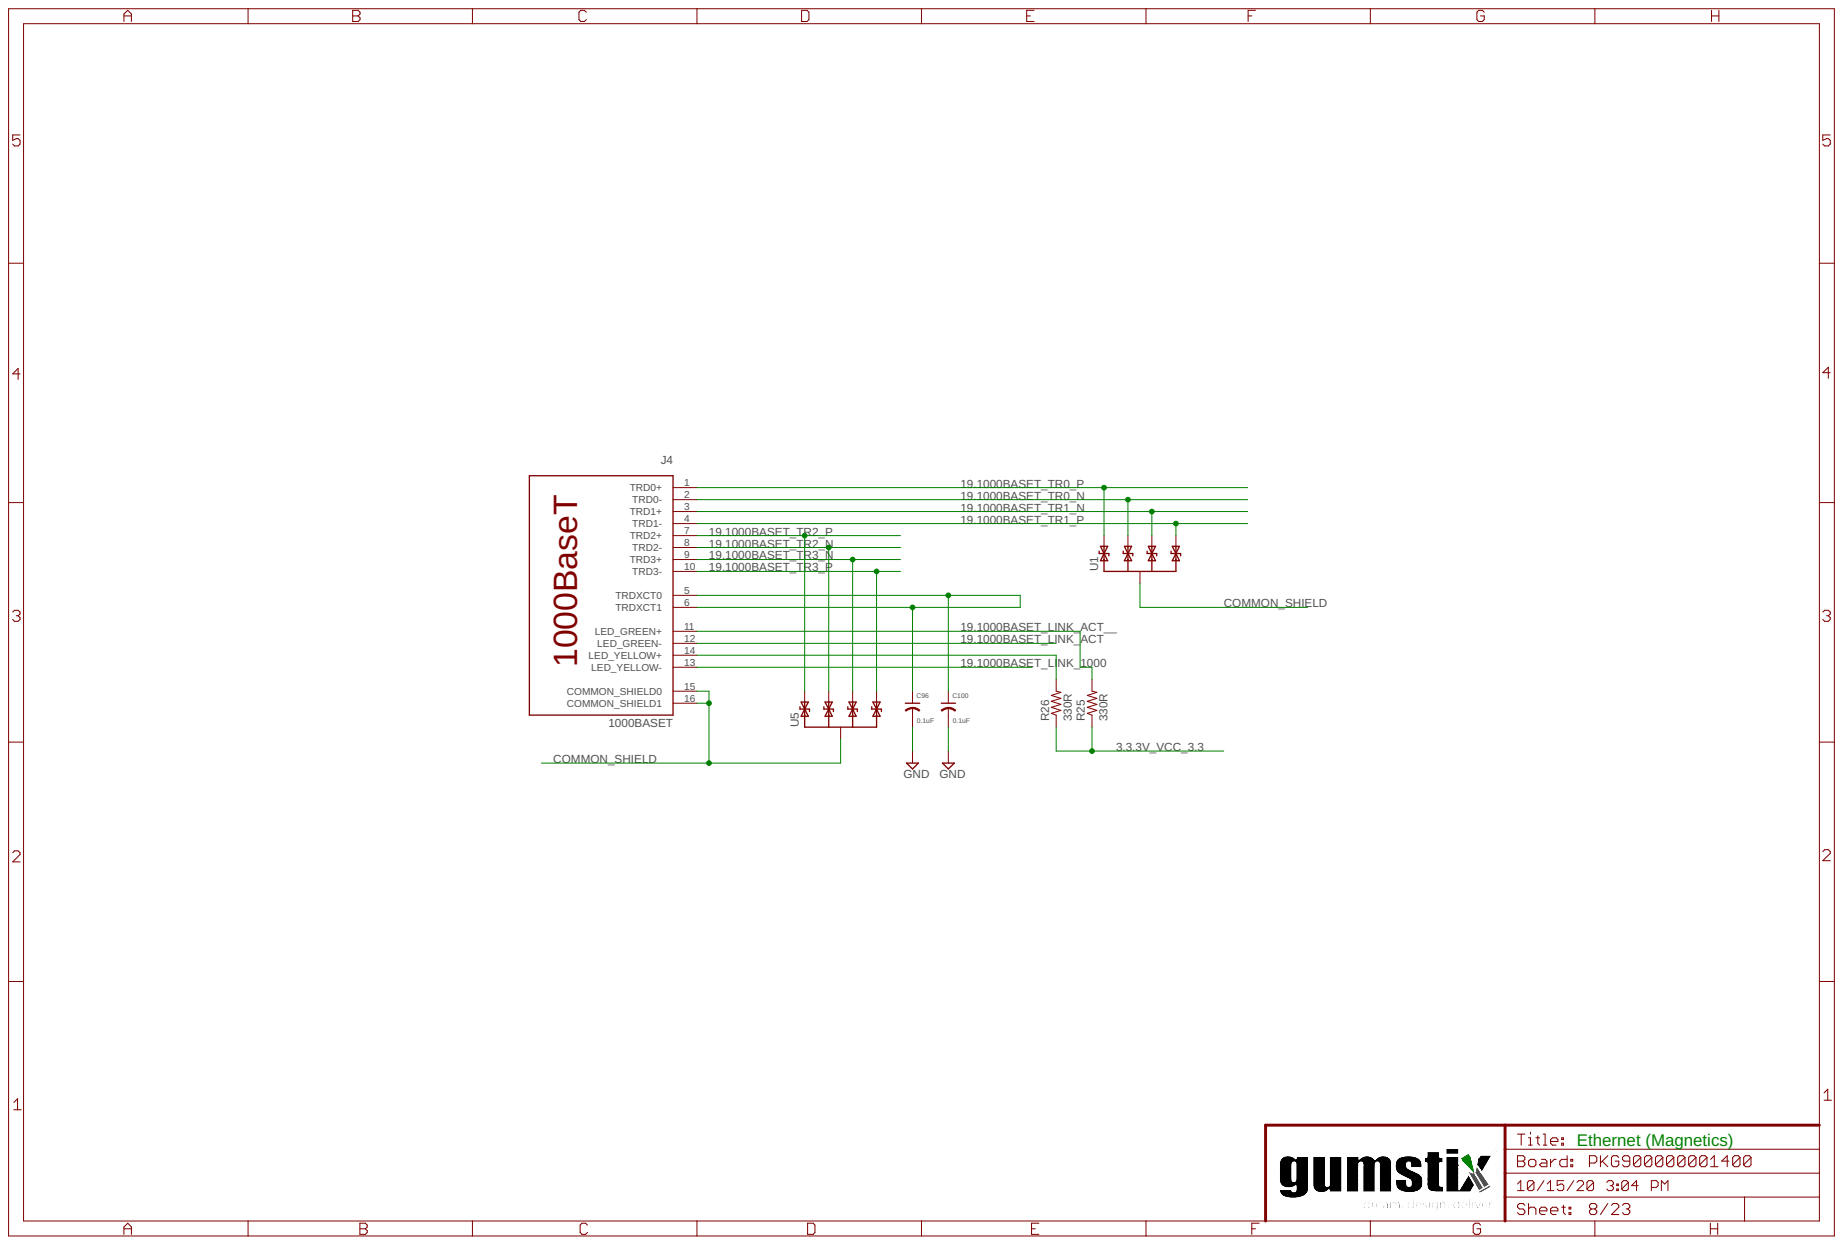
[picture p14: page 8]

3 TRD1-4 19.1000BASET_TR1_N

7 TRD2-8 TRD3+ 5 TRDXCT1

19.1000BASET_TR1_P

19.1000BASET_LINK_1000

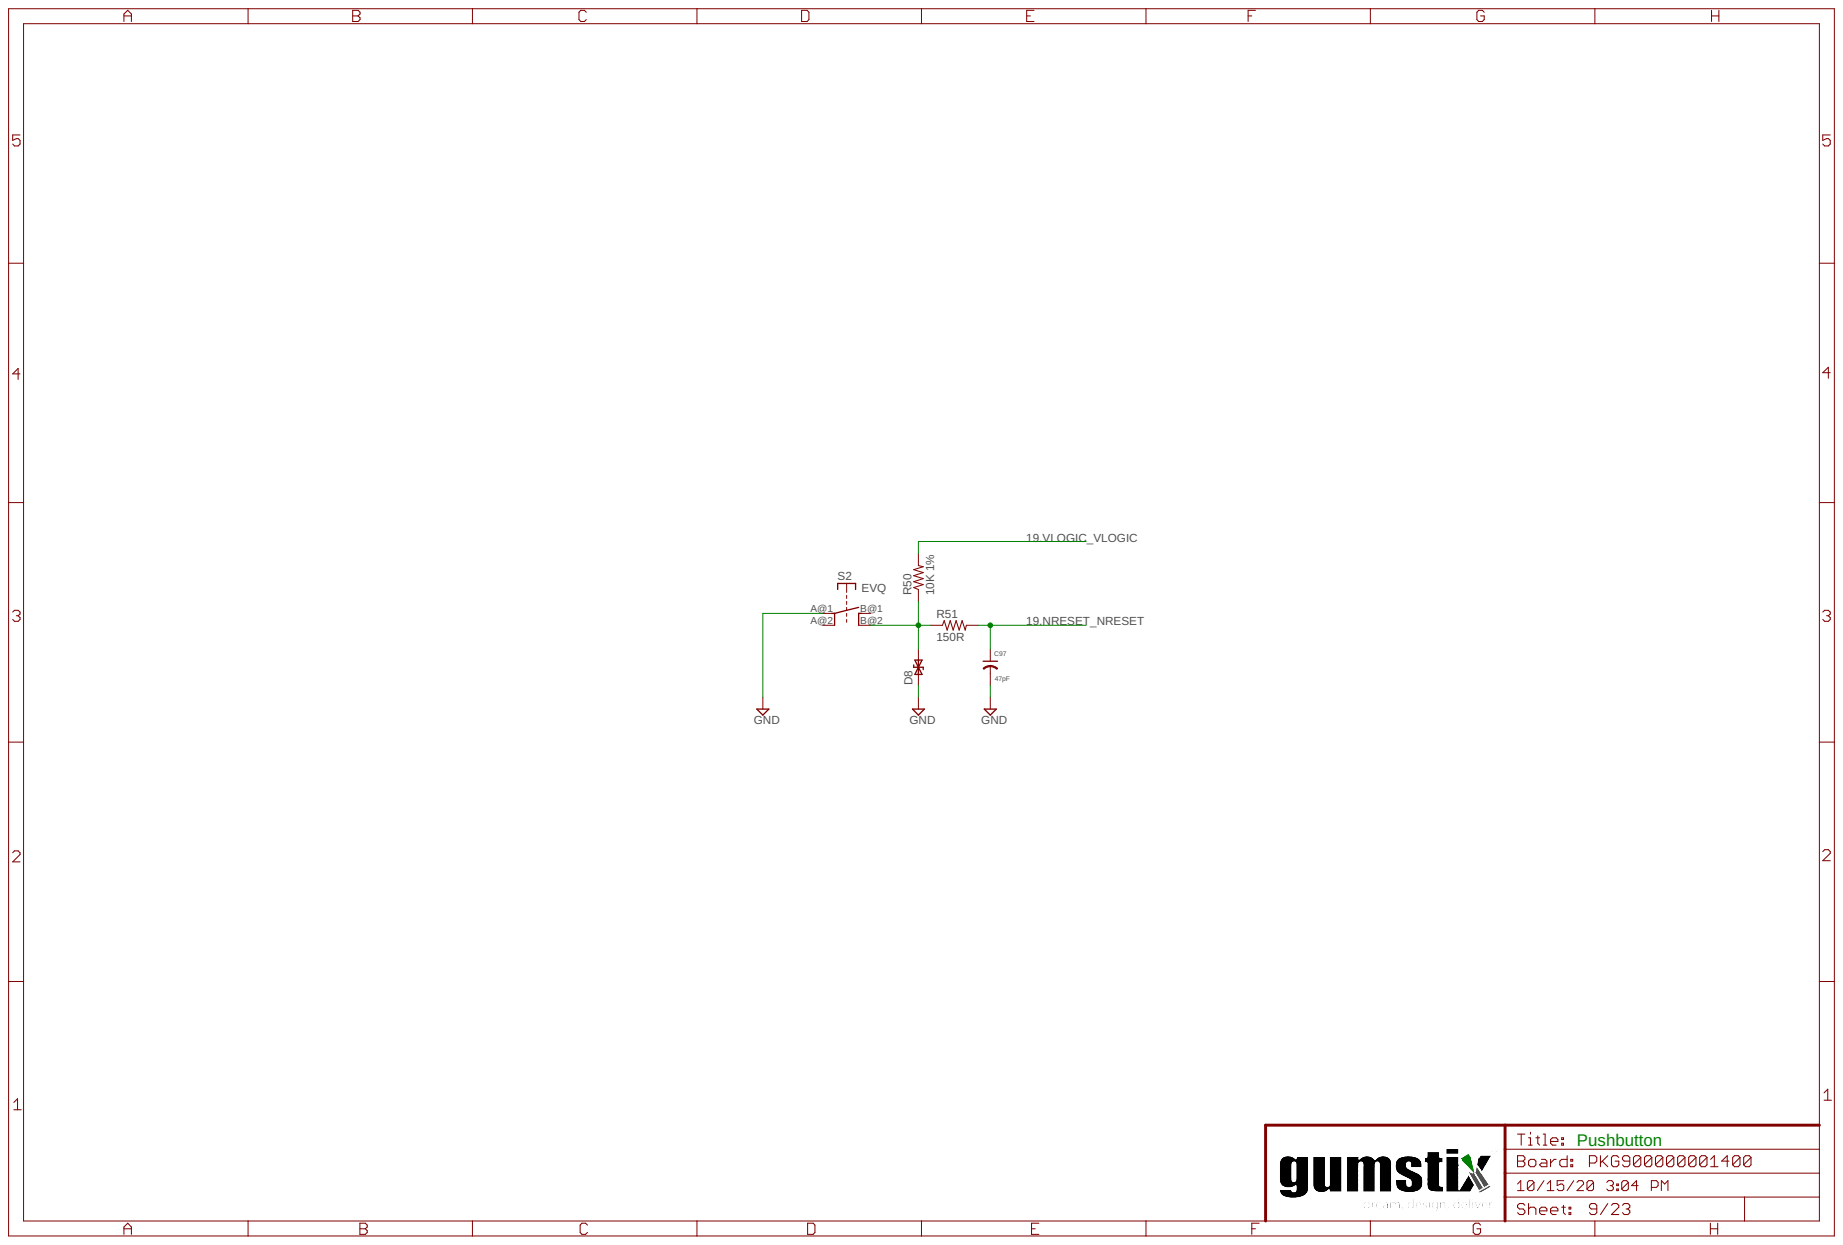
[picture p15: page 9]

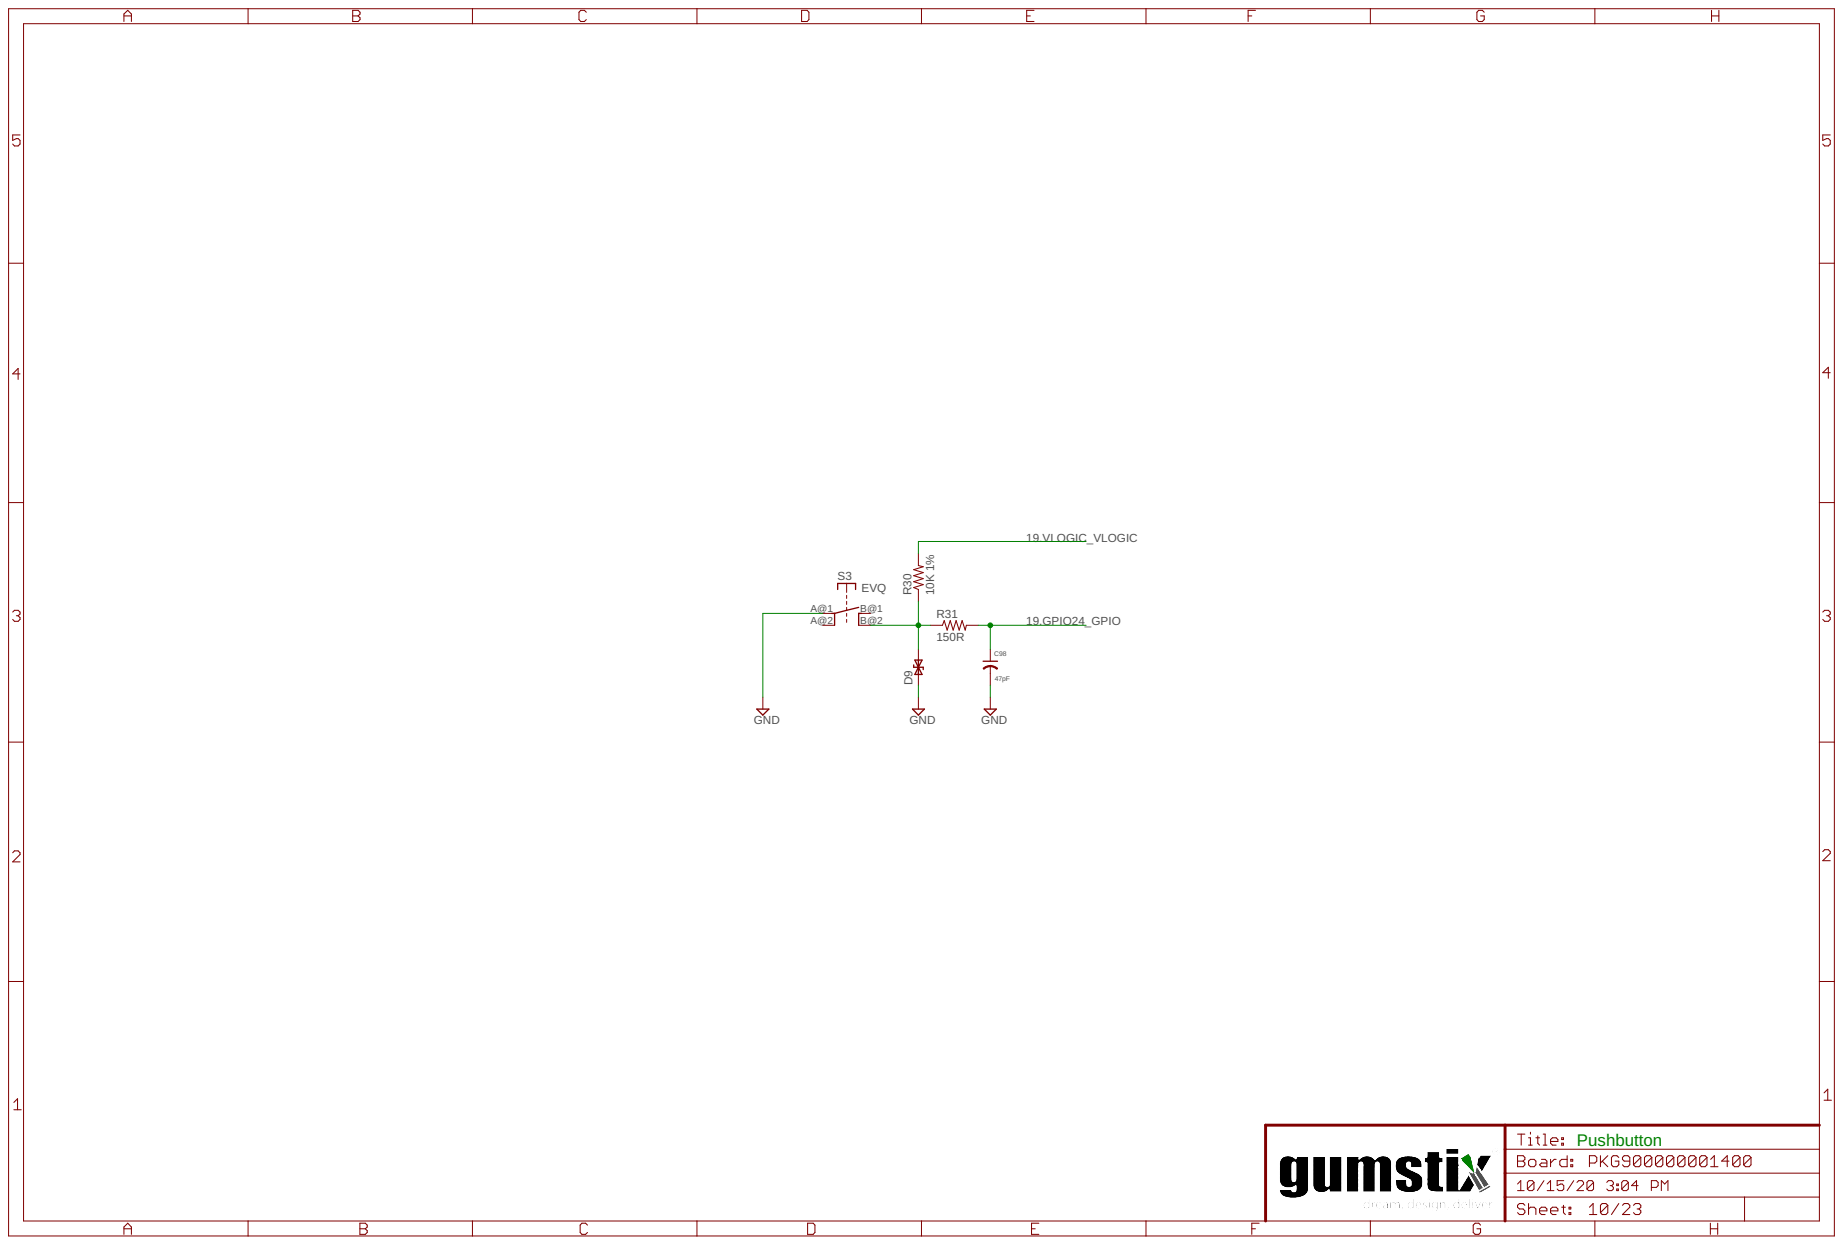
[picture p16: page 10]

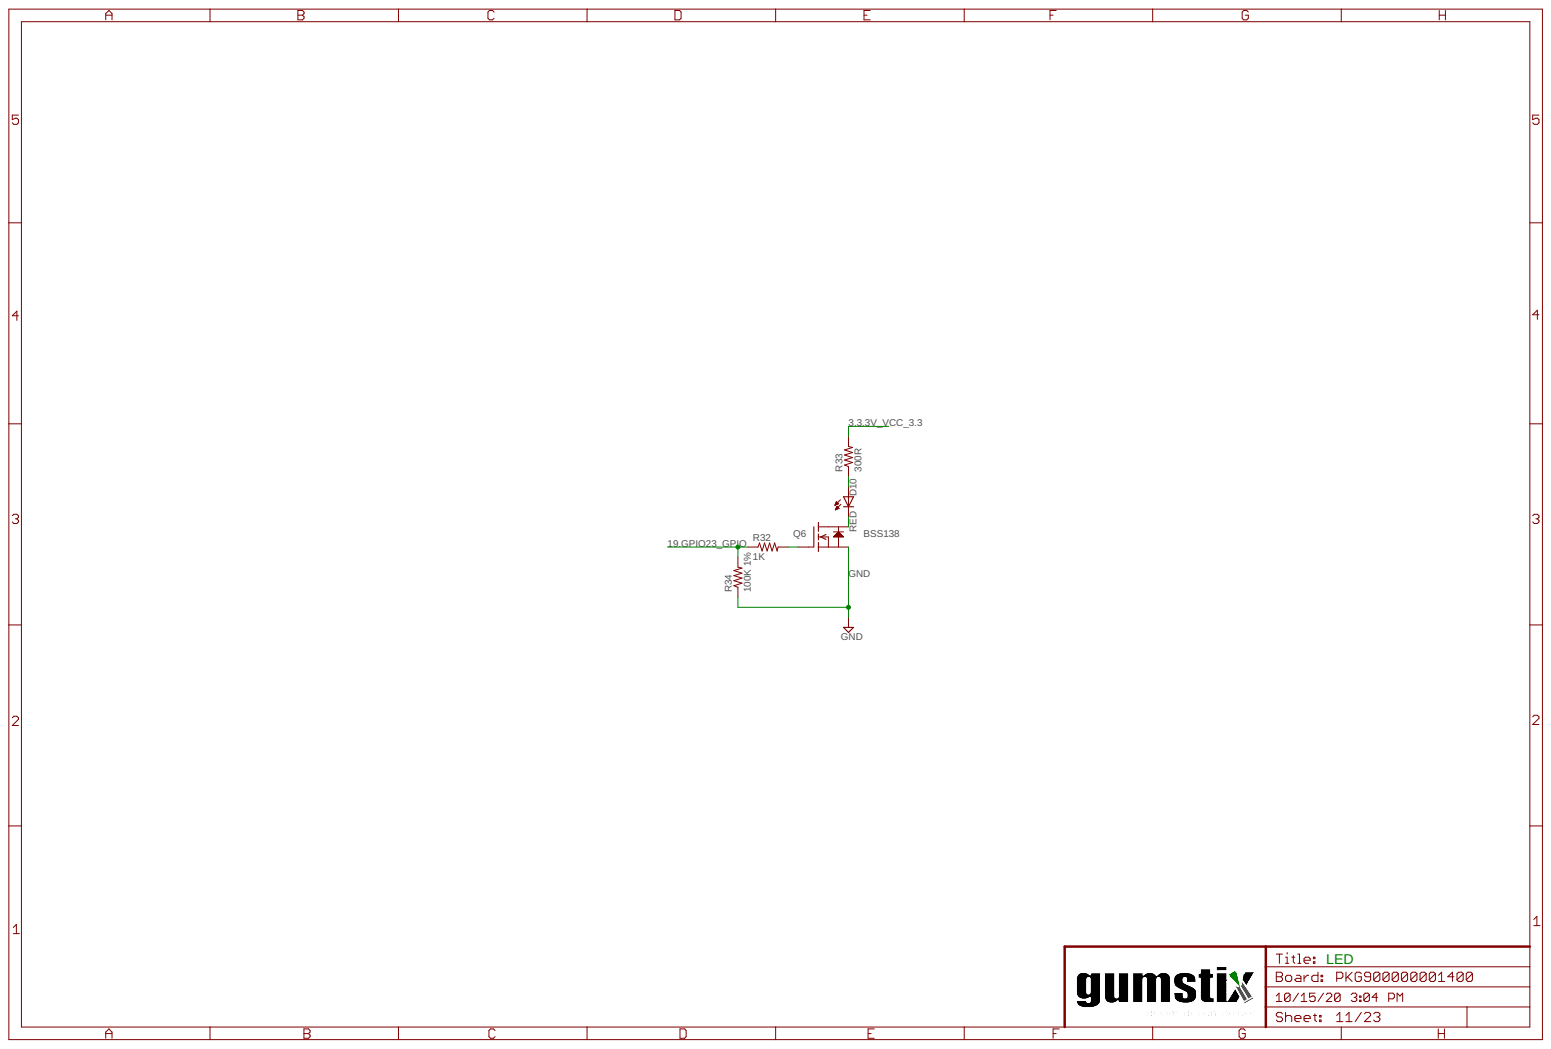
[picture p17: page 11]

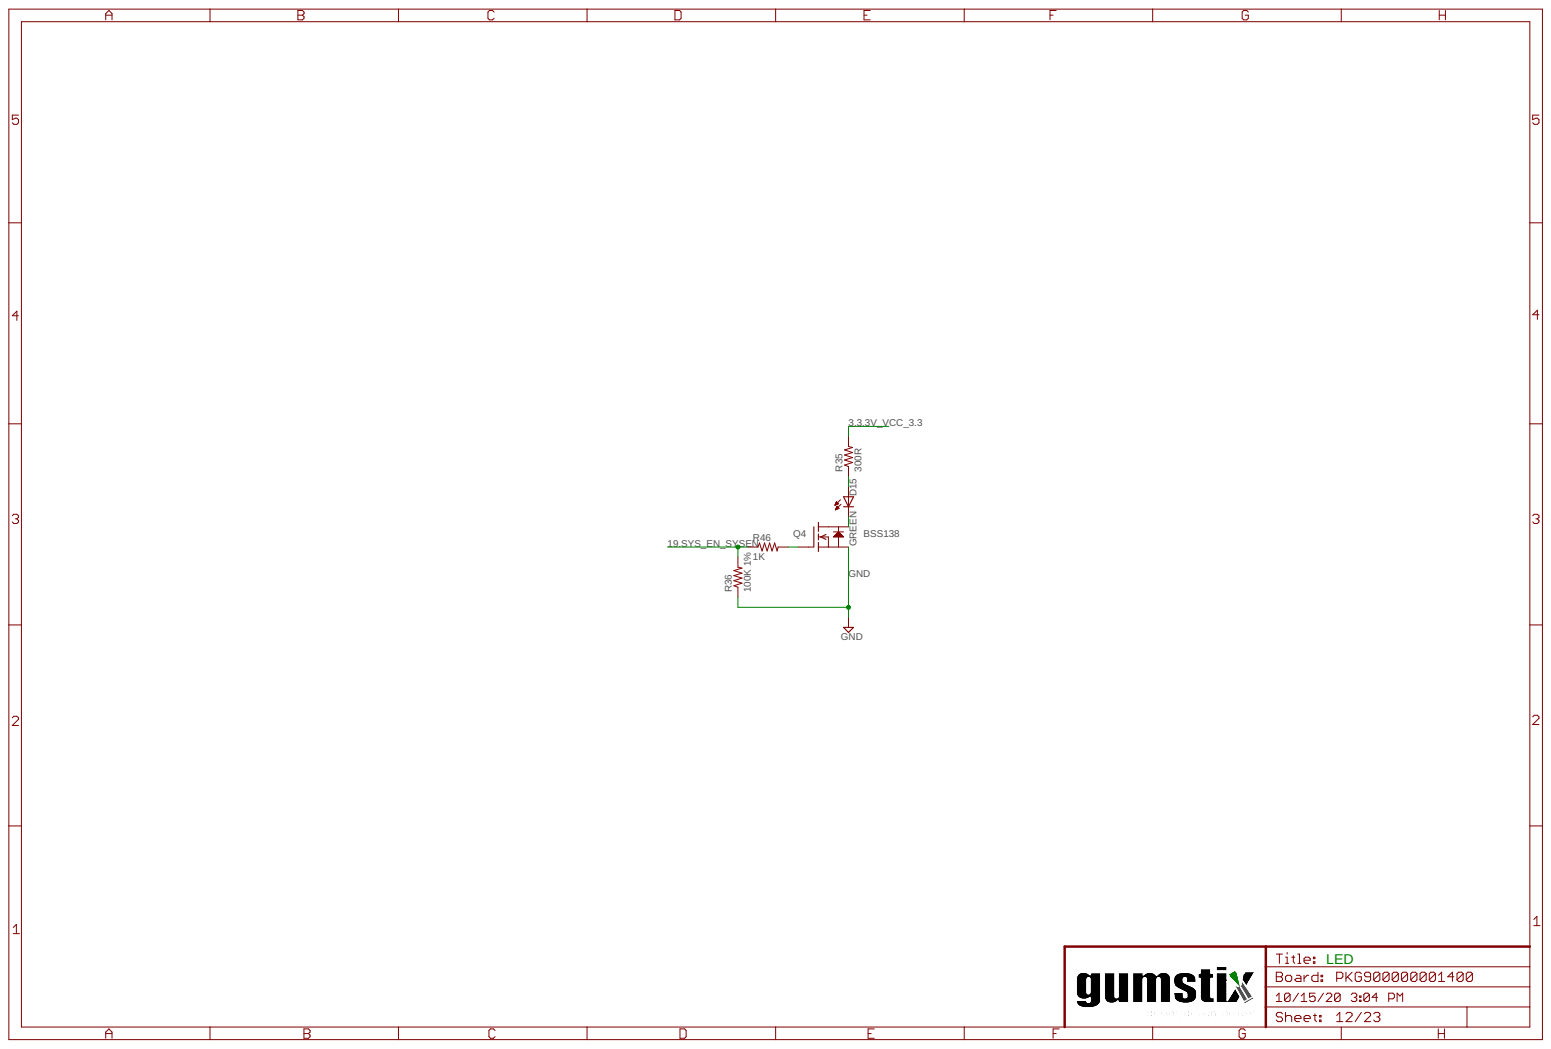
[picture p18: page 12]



PWR<->GND via stitching
around bottom side signals
(per Toradex layout guidelines)

TPD13S523 sheet says
to GND unused pins with
75ohm resistor.








RPi CSI Vertical Connector


RPi CSI Vertical Connector


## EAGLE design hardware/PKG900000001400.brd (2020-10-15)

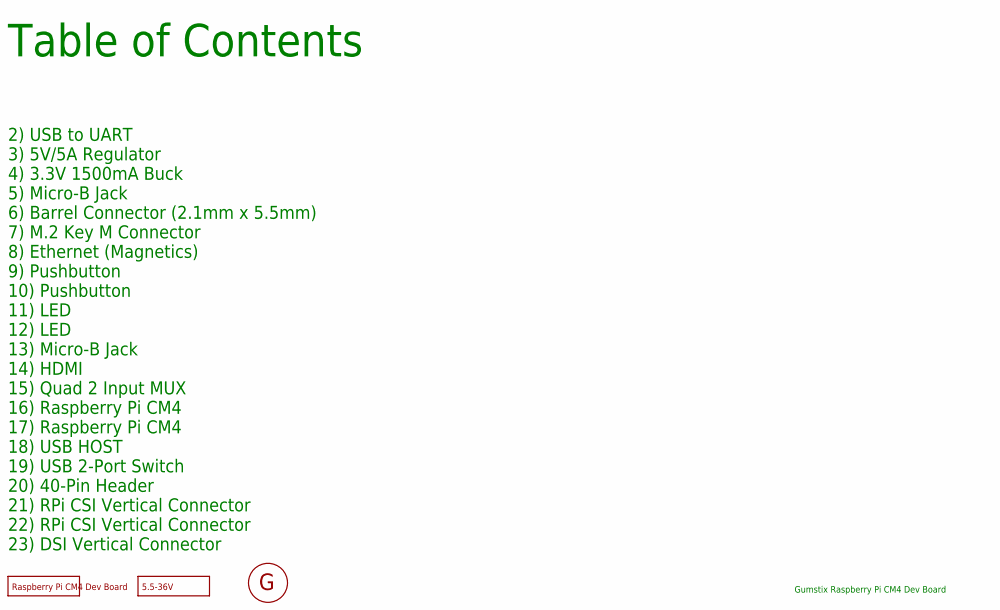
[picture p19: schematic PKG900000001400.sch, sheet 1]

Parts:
FD1, FD2, FD3, FD4, FD5, FD6, FD7, FD8: DNP; FIDUCIAL
U$3: DNP; GEPPETTO_LABEL
U$4: DNP; GEPPETTO_LOGO_SILK10
U$6: DNP; TIP_POSITIVE_LABEL; VOLTAGE 5.5-36V

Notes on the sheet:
Table of Contents
Gumstix Raspberry Pi CM4 Dev Board
2) USB to UART
3) 5V/5A Regulator
4) 3.3V 1500mA Buck
5) Micro-B Jack
6) Barrel Connector (2.1mm x 5.5mm)
7) M.2 Key M Connector
8) Ethernet (Magnetics)
9) Pushbutton
10) Pushbutton
11) LED
12) LED
13) Micro-B Jack
14) HDMI
15) Quad 2 Input MUX
16) Raspberry Pi CM4
17) Raspberry Pi CM4
18) USB HOST
19) USB 2-Port Switch
20) 40-Pin Header
21) RPi CSI Vertical Connector
22) RPi CSI Vertical Connector
23) DSI Vertical Connector

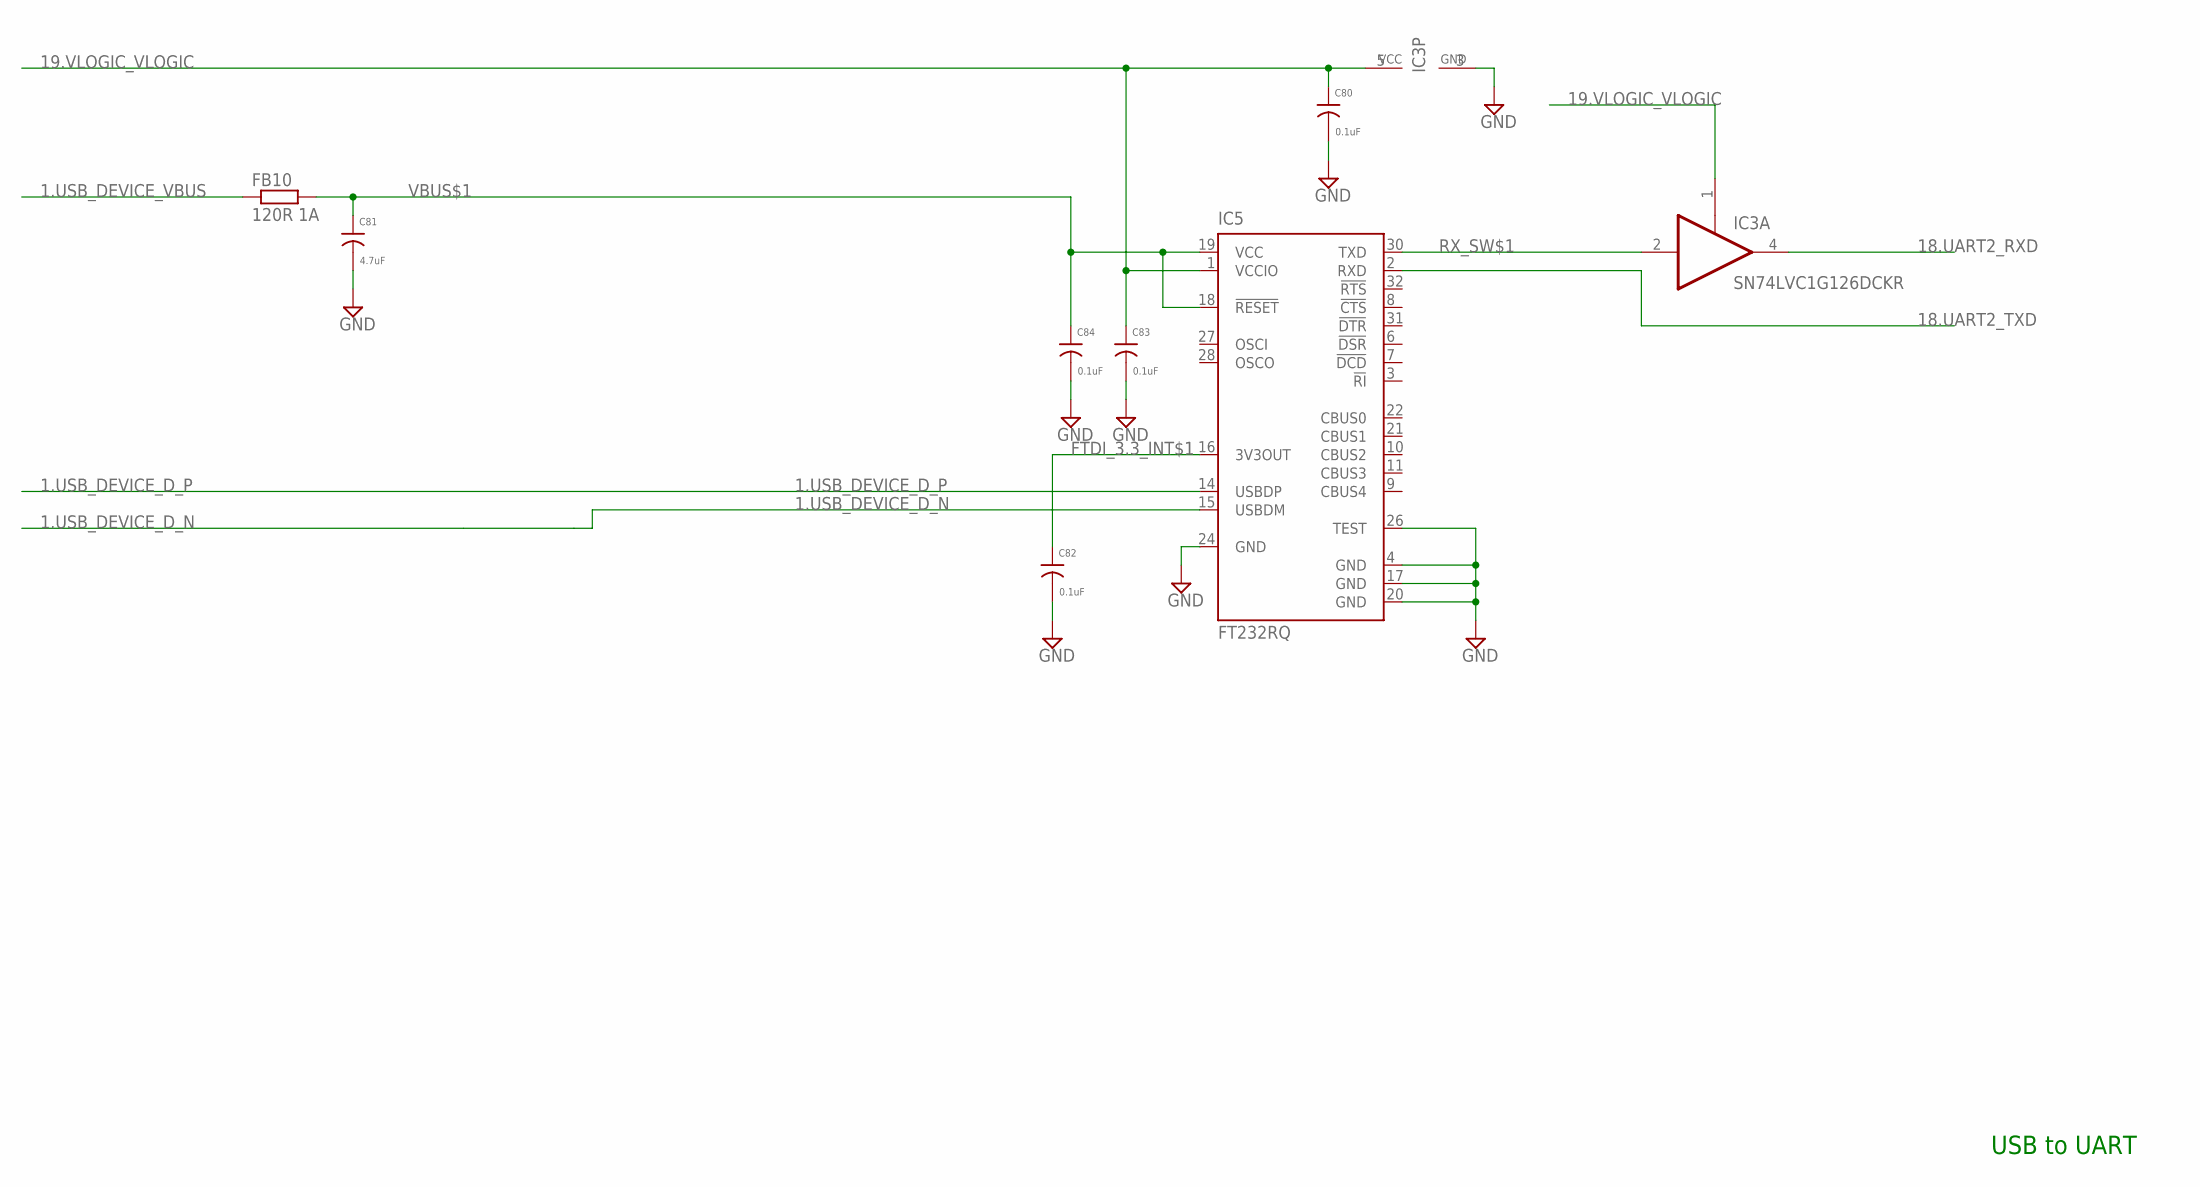
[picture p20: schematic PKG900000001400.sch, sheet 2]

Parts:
C80, C82, C83, C84: 0.1uF; 0201
C81: 4.7uF; 0603
FB10: 120R 1A; 0402
IC3: SN74LVC1G126DCKR; SC70-5
IC5: FT232RQ; QFN32

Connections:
1.USB_DEVICE_D_N: IC5.15 (USBDM); also elsewhere on the board
1.USB_DEVICE_D_P: IC5.14 (USBDP); also elsewhere on the board
1.USB_DEVICE_VBUS: FB10.1; also elsewhere on the board
18.UART2_RXD: IC3.4 (O); also elsewhere on the board
18.UART2_TXD: IC5.2 (RXD); also elsewhere on the board
19.VLOGIC_VLOGIC: C80.1, C83.1, IC3.1 (OE), IC3.5 (VCC), IC5.1 (VCCIO); also elsewhere on the board
FTDI_3.3_INT$1: C82.1, IC5.16 (3V3OUT)
GND: C80.2, C81.2, C82.2, C83.2, C84.2, IC3.3 (GND), IC5.4 (GND), IC5.17 (GND), IC5.20 (GND), IC5.24 (GND), IC5.26 (TEST); also elsewhere on the board
RX_SW$1: IC3.2 (I), IC5.30 (TXD)
VBUS$1: C81.1, C84.1, FB10.2, IC5.18 (!RESET), IC5.19 (VCC)

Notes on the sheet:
USB to UART

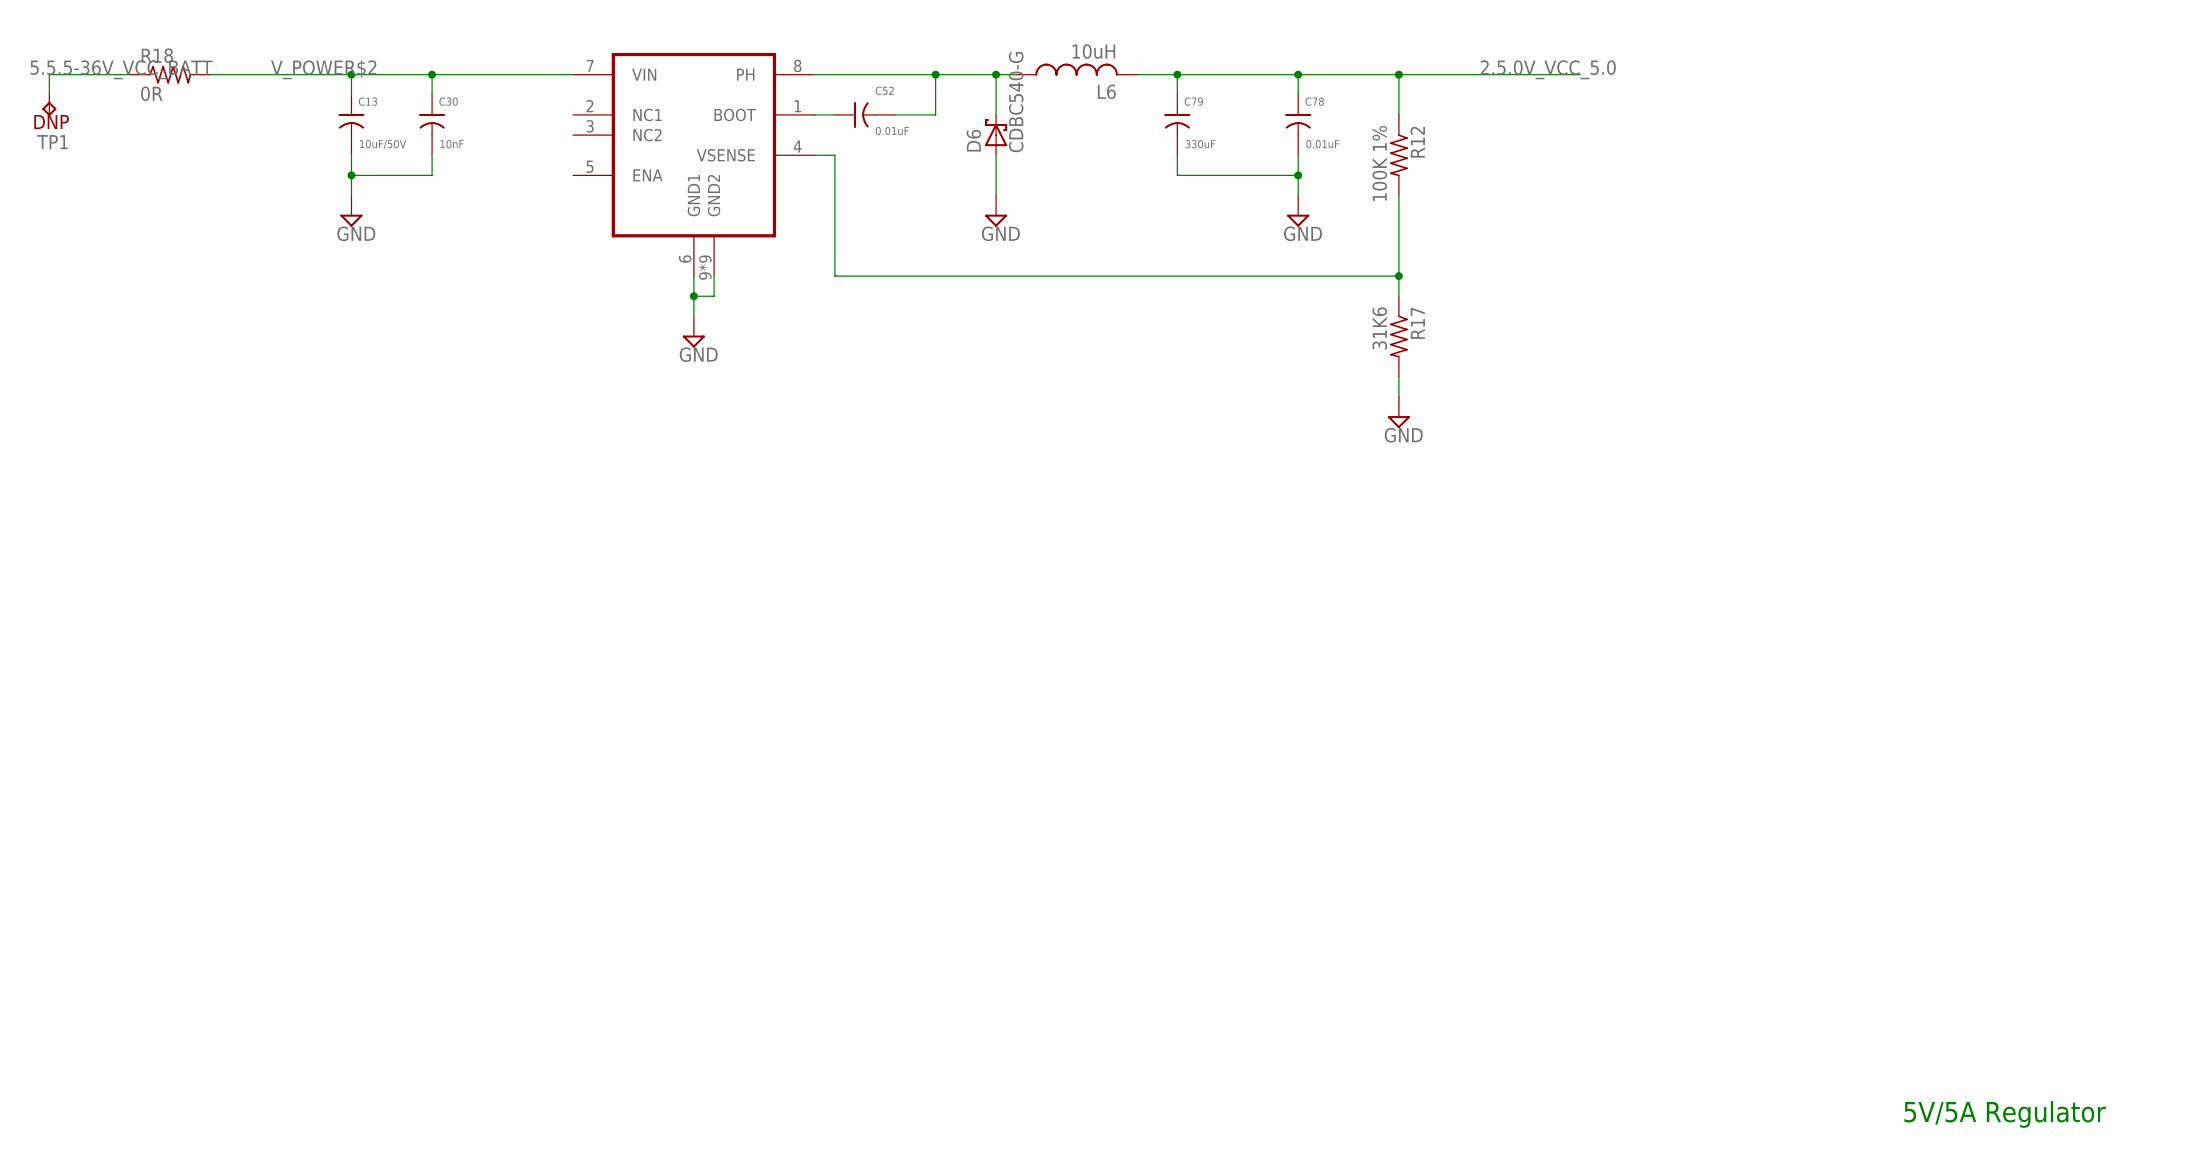
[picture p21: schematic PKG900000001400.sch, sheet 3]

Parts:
C13: 10uF/50V; 1206
C30: 10nF; 0603
C52, C78: 0.01uF; 0201
C79: 330uF; PANASONIC_F
D6: CDBC540-G; DO-214AB
L6: 10uH; 3232DZ
R12: 100K 1%; 0201
R17: 31K6; 0402
R18: 0R; 0805
TP1: DNP; TP0500
U7: TPS5450; 8SO_POWERPAD

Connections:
2.5.0V_VCC_5.0: C78.1, C79.+ (1), L6.2, R12.1; also elsewhere on the board
5.5.5-36V_VCC_BATT: R18.1, TP1.1; also elsewhere on the board
BOOT$2: C52.1, U7.1 (BOOT)
GND: C13.2, C30.2, C78.2, C79.- (2), D6.A, R17.2, U7.6 (GND1), U7.9 (GND2), U7.PWRPAD1 (GND2), U7.PWRPAD2 (GND2), U7.PWRPAD3 (GND2), U7.PWRPAD4 (GND2), U7.PWRPAD5 (GND2), U7.PWRPAD6 (GND2), U7.PWRPAD7 (GND2), U7.PWRPAD8 (GND2); also elsewhere on the board
PH$2: C52.2, D6.C, L6.1, U7.8 (PH)
VSENSE$2: R12.2, R17.1, U7.4 (VSENSE)
V_POWER$2: C13.1, C30.1, R18.2, U7.7 (VIN)

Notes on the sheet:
5V/5A Regulator

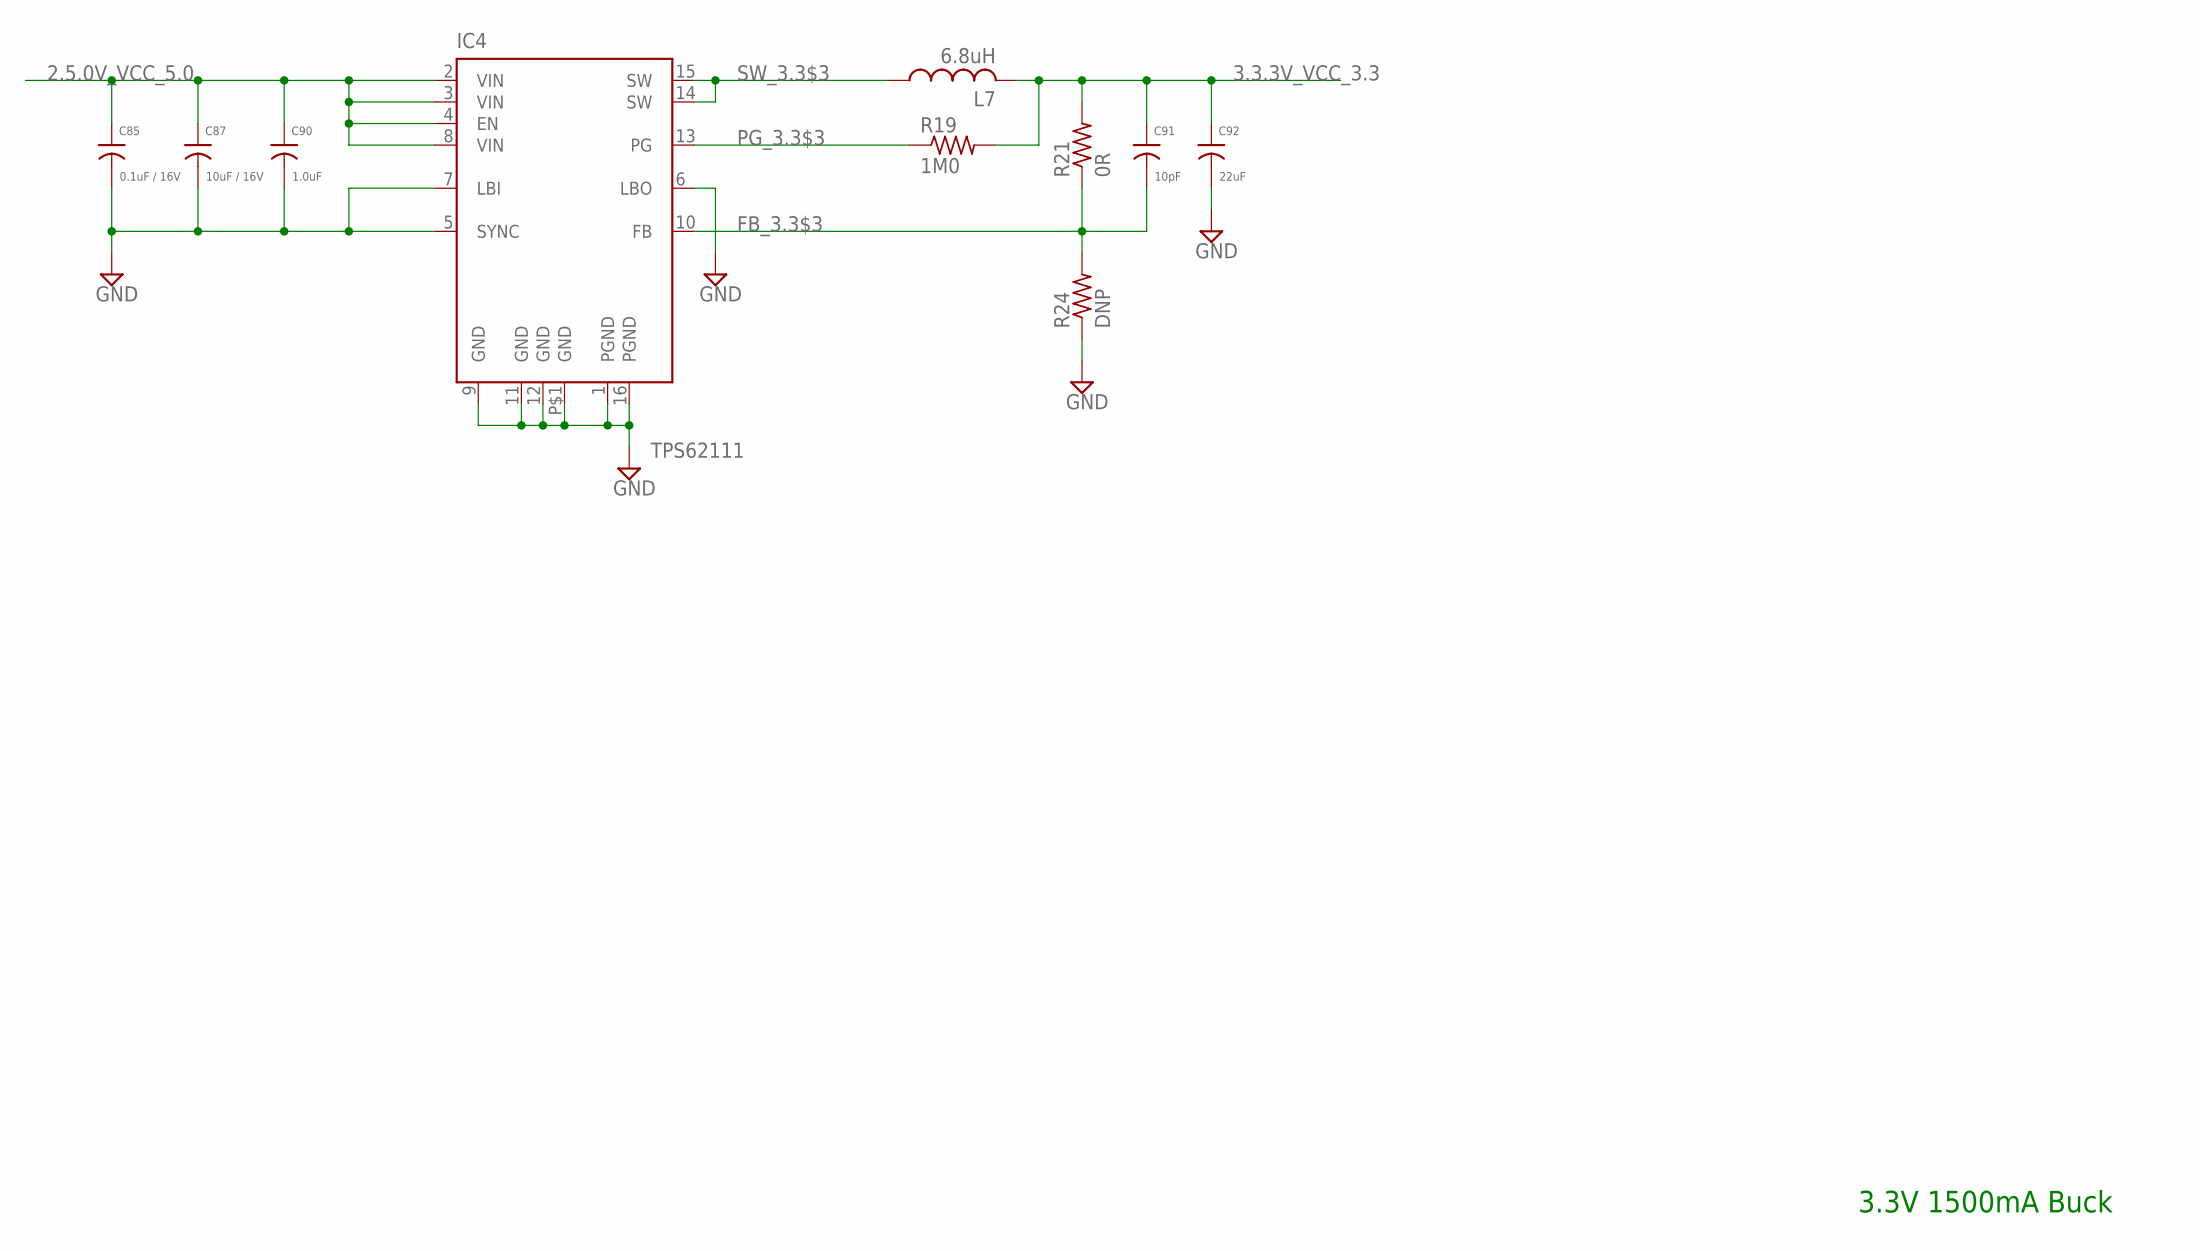
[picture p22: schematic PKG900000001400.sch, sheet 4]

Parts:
C85: 0.1uF / 16V; 0402
C87: 10uF / 16V; 0805
C90: 1.0uF; 0402
C91: 10pF; 0201
C92: 22uF; 0805
IC4: TPS62111; PQFP16
L7: 6.8uH; 1515
R19: 1M0; 0201
R21: 0R; 0402
R24: DNP; 0402

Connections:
2.5.0V_VCC_5.0: C85.1, C87.1, C90.1, IC4.2 (VIN), IC4.3 (VIN), IC4.4 (EN), IC4.8 (VIN); also elsewhere on the board
3.3.3V_VCC_3.3: C91.1, C92.1, L7.2, R19.2, R21.2; also elsewhere on the board
FB_3.3$3: C91.2, IC4.10 (FB), R21.1, R24.2
GND: C85.2, C87.2, C90.2, C92.2, IC4.1 (PGND), IC4.5 (SYNC), IC4.6 (LBO), IC4.7 (LBI), IC4.9 (GND), IC4.11 (GND), IC4.12 (GND), IC4.16 (PGND), IC4.P$1 (GND), R24.1; also elsewhere on the board
PG_3.3$3: IC4.13 (PG), R19.1
SW_3.3$3: IC4.14 (SW), IC4.15 (SW), L7.1

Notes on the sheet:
3.3V 1500mA Buck

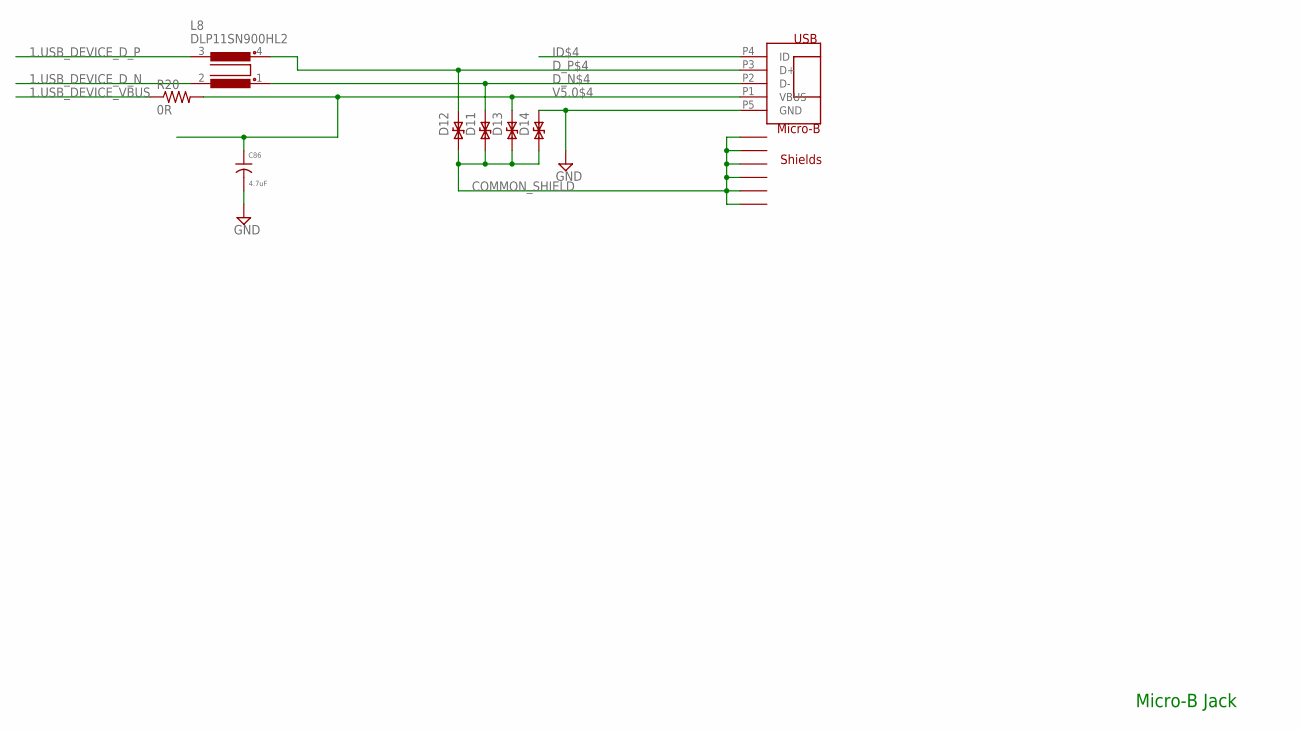
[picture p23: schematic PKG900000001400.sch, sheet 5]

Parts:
C86: 4.7uF; 0603
D11, D12: PS04LTVA1; D0402
D13, D14: B72590D50A060; D0402
J6: USB_MICRO_B
L8: DLP11SN900HL2; 0504-DLP11S
R20: 0R; 0201

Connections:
1.USB_DEVICE_D_N: L8.2; also elsewhere on the board
1.USB_DEVICE_D_P: L8.3; also elsewhere on the board
1.USB_DEVICE_VBUS: R20.1; also elsewhere on the board
COMMON_SHIELD: D11.P1, D12.P1, D13.P1, D14.P1, J6.COMMON_SHEILD1 (COMMON_SHIELD1), J6.COMMON_SHEILD2 (COMMON_SHIELD2), J6.COMMON_SHEILD3 (COMMON_SHIELD3), J6.COMMON_SHEILD4 (COMMON_SHIELD4), J6.COMMON_SHEILD5 (COMMON_SHIELD5), J6.COMMON_SHEILD6 (COMMON_SHIELD6); also elsewhere on the board
D_N$4: D11.P2, J6.P2 (D-), L8.1
D_P$4: D12.P2, J6.P3 (D+), L8.4
GND: C86.2, D14.P2, J6.P5 (GND); also elsewhere on the board
ID$4: J6.P4 (ID)
V5.0$4: C86.1, D13.P2, J6.P1 (VBUS), R20.2

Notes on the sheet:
Micro-B Jack

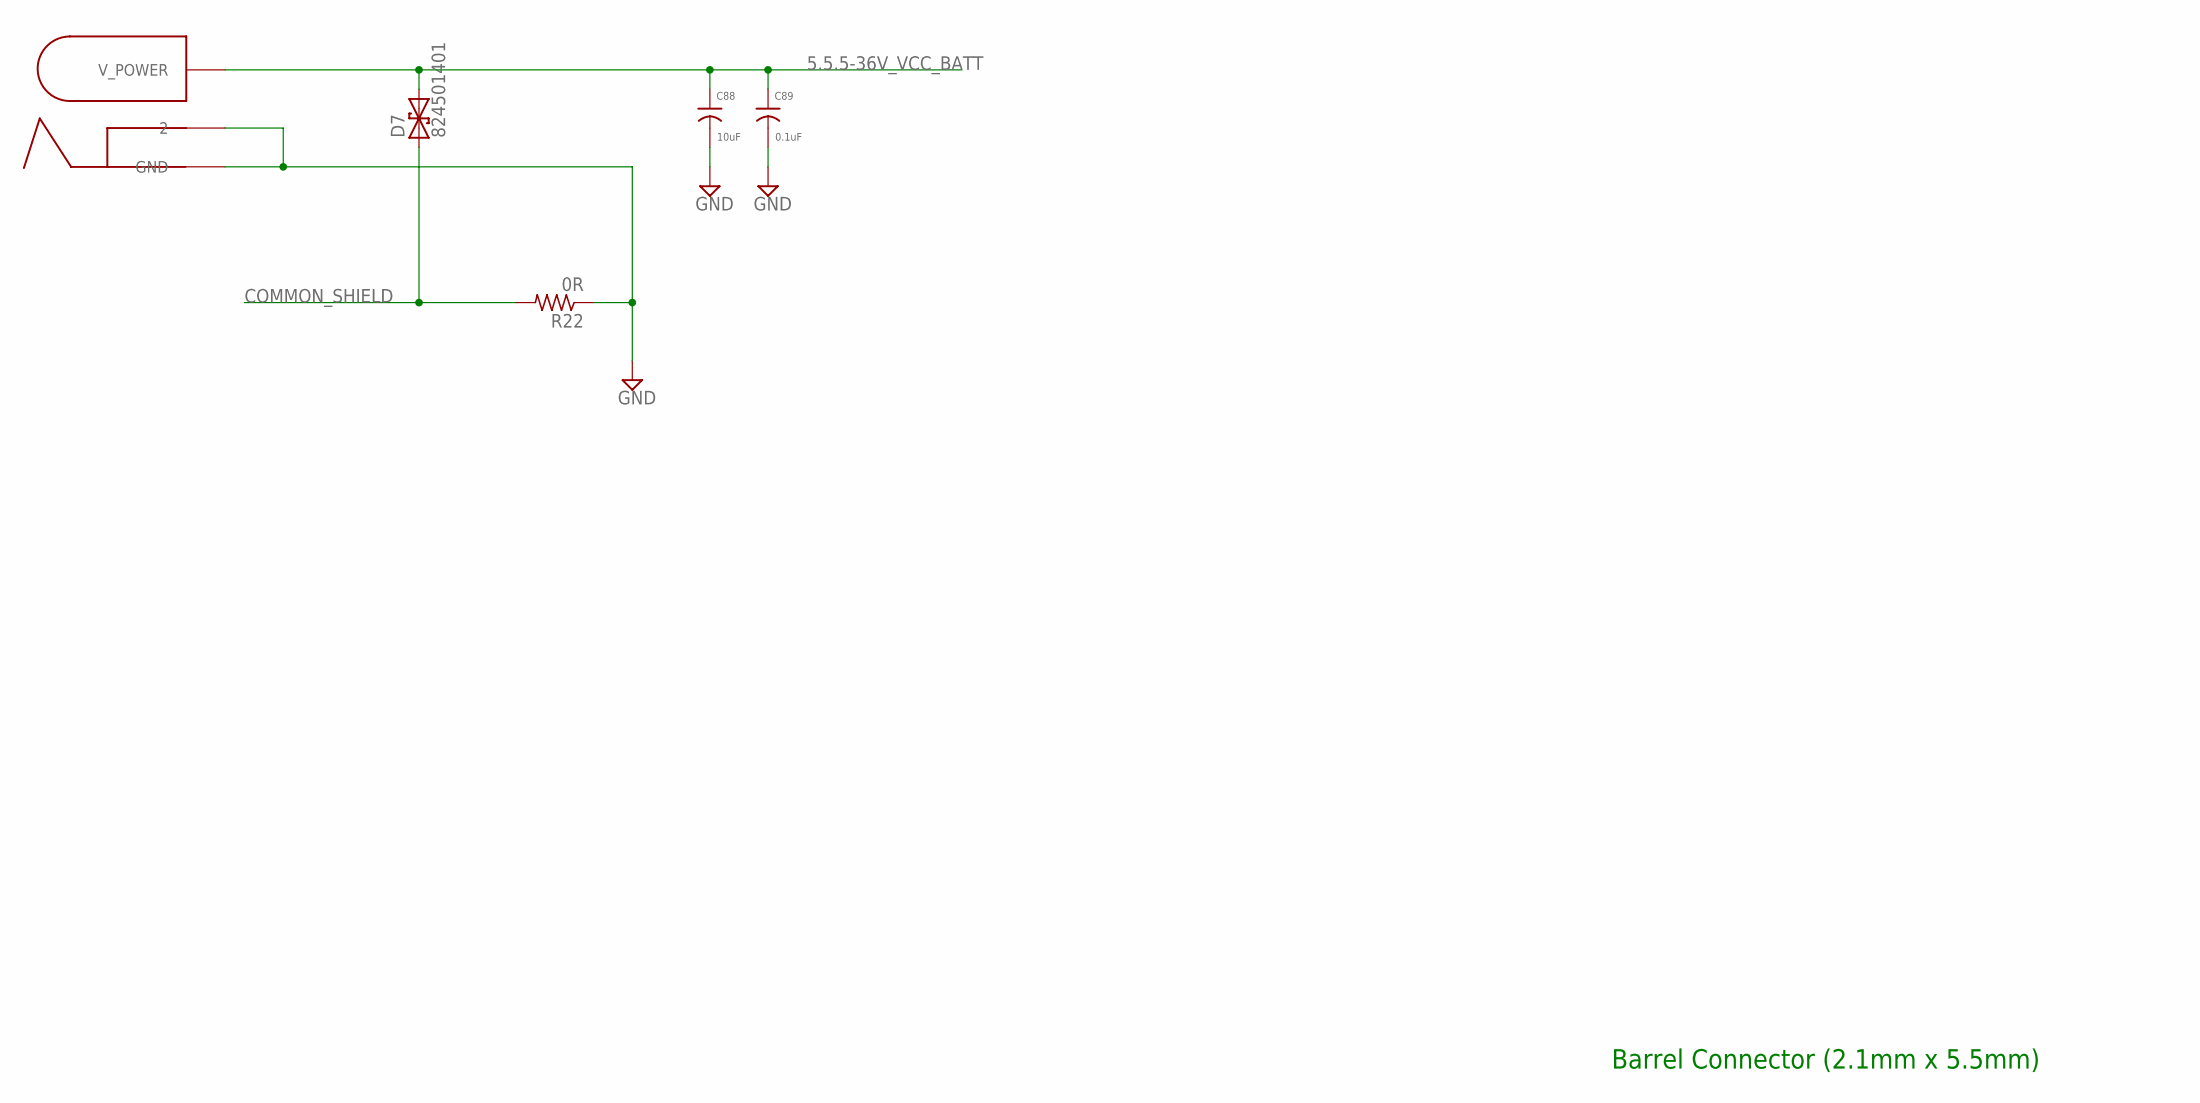
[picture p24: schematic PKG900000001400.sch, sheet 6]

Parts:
C88: 10uF; 0603
C89: 0.1uF; 0201
D7: 824501401; SMAJ
J3: PJ-002A
R22: 0R; 0201

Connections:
5.5.5-36V_VCC_BATT: C88.1, C89.1, D7.C (2), J3.1 (V_POWER); also elsewhere on the board
COMMON_SHIELD: D7.A (1), R22.2; also elsewhere on the board
GND: C88.2, C89.2, J3.2 (GND), J3.3 (2), R22.1; also elsewhere on the board

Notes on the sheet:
Barrel Connector (2.1mm x 5.5mm)

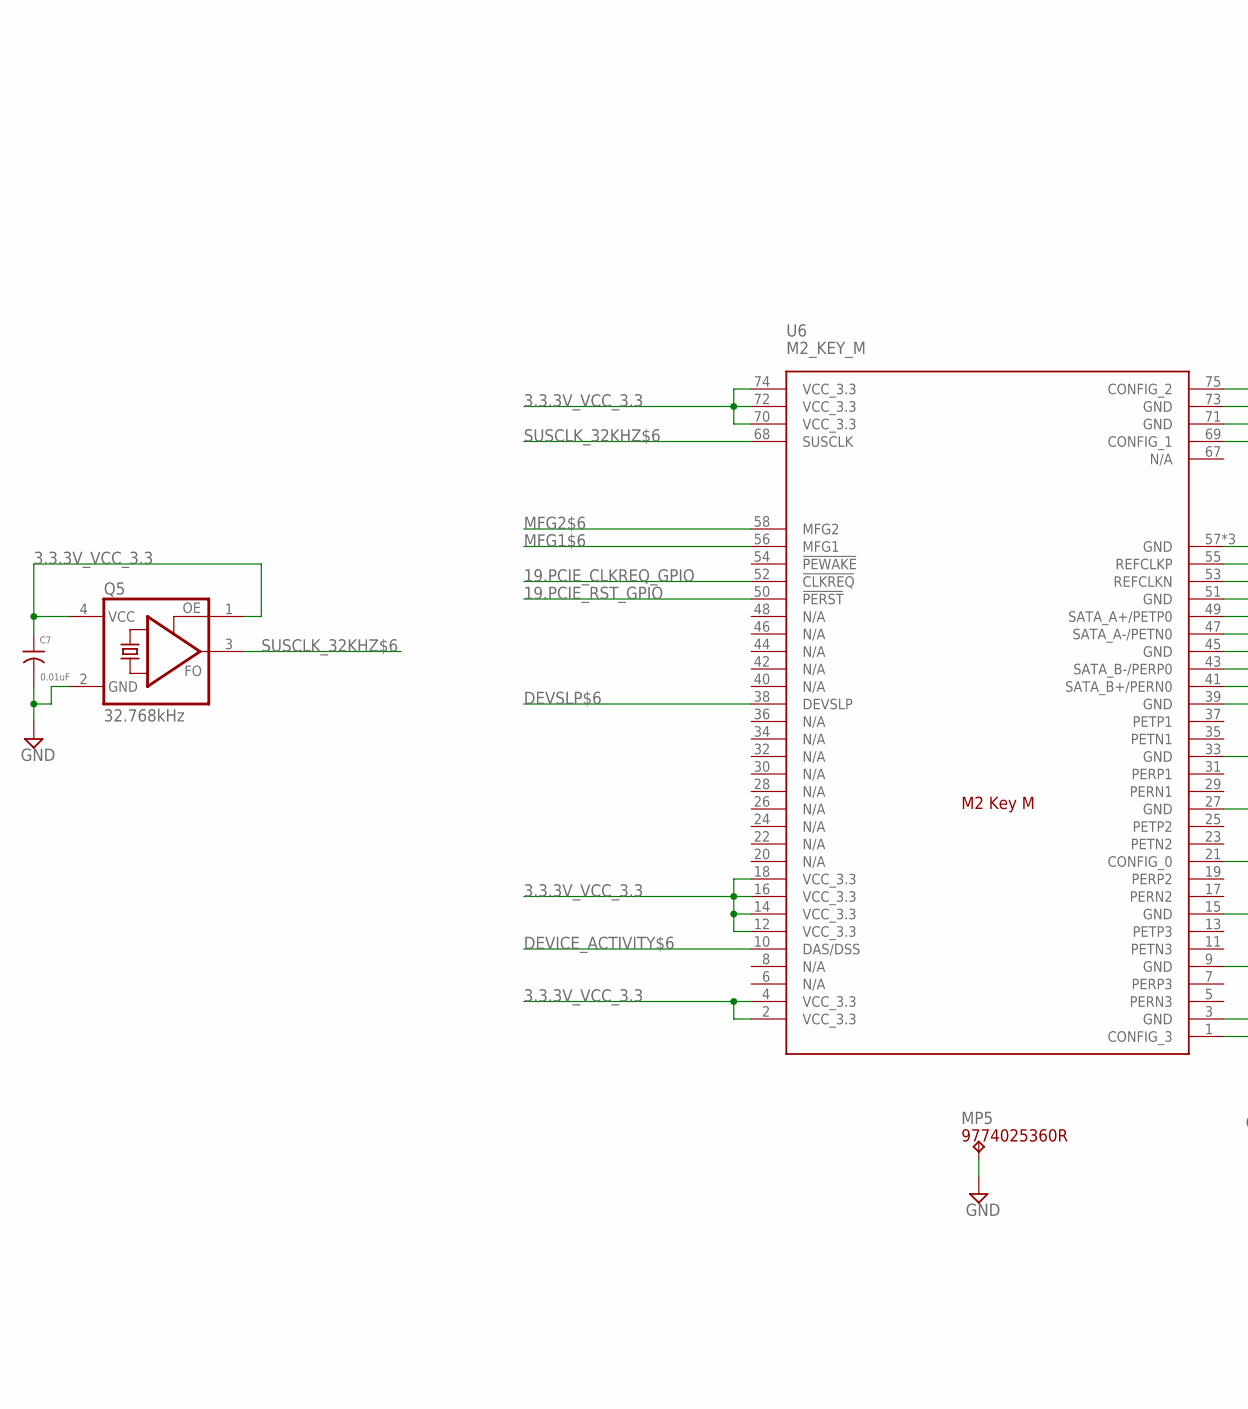
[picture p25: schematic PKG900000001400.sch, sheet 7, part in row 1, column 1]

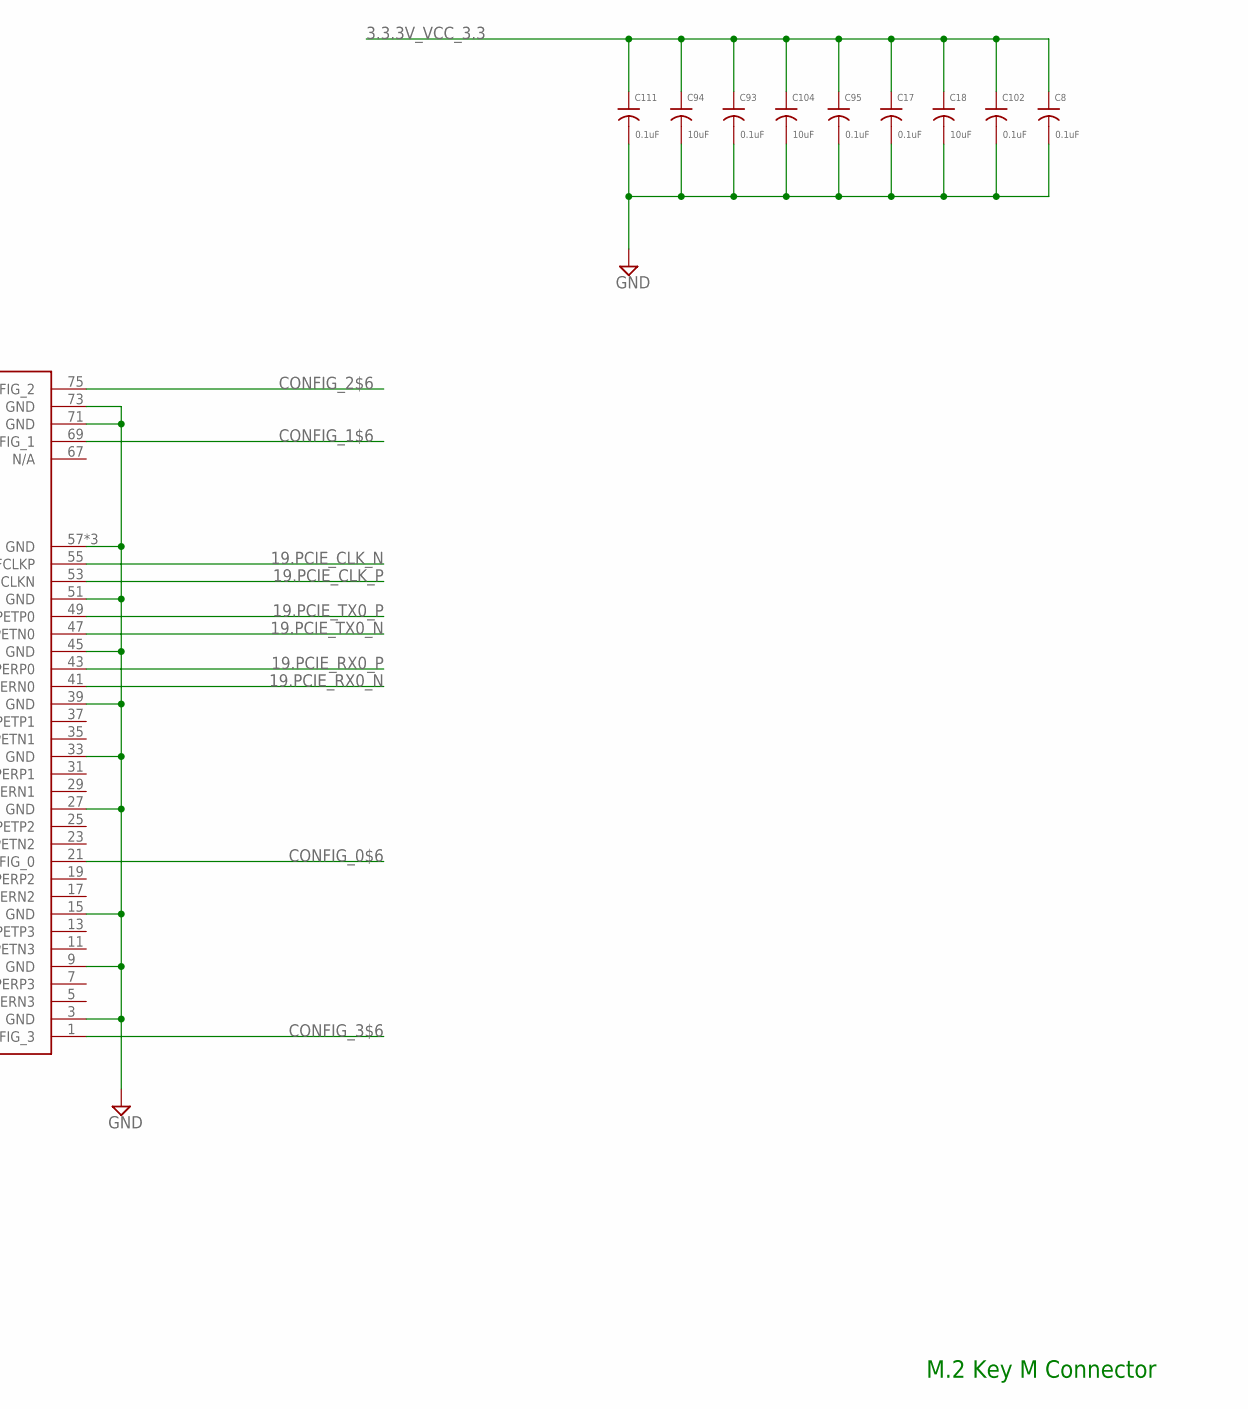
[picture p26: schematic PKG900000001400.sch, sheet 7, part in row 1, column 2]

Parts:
C7: 0.01uF; 0201
C8, C17, C93, C95, C102, C111: 0.1uF; 0201
C18, C94, C104: 10uF; 0603
MP5: 9774025360R; WA-SMSI_9774___360
Q5: 32.768kHz; VLGA-4
U6: M2_KEY_M; 2199230_KEY_M

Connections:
3.3.3V_VCC_3.3: C7.1, C8.1, C17.1, C18.1, C93.1, C94.1, C95.1, C102.1, C104.1, C111.1, Q5.1 (OE), Q5.4 (VCC), U6.2 (VCC_3.3), U6.4 (VCC_3.3), U6.12 (VCC_3.3), U6.14 (VCC_3.3), U6.16 (VCC_3.3), U6.18 (VCC_3.3), U6.70 (VCC_3.3), U6.72 (VCC_3.3), U6.74 (VCC_3.3); also elsewhere on the board
19.PCIE_CLKREQ_GPIO: U6.52 (!CLKREQ); also elsewhere on the board
19.PCIE_CLK_N: U6.55 (REFCLKP); also elsewhere on the board
19.PCIE_CLK_P: U6.53 (REFCLKN); also elsewhere on the board
19.PCIE_RST_GPIO: U6.50 (!PERST); also elsewhere on the board
19.PCIE_RX0_N: U6.41 (SATA_B+/PERN0); also elsewhere on the board
19.PCIE_RX0_P: U6.43 (SATA_B-/PERP0); also elsewhere on the board
19.PCIE_TX0_N: U6.47 (SATA_A-/PETN0); also elsewhere on the board
19.PCIE_TX0_P: U6.49 (SATA_A+/PETP0); also elsewhere on the board
CONFIG_0$6: U6.21 (CONFIG_0)
CONFIG_1$6: U6.69 (CONFIG_1)
CONFIG_2$6: U6.75 (CONFIG_2)
CONFIG_3$6: U6.1 (CONFIG_3)
DEVICE_ACTIVITY$6: U6.10 (DAS/DSS)
DEVSLP$6: U6.38 (DEVSLP)
GND: C7.2, C8.2, C17.2, C18.2, C93.2, C94.2, C95.2, C102.2, C104.2, C111.2, MP5.1, Q5.2 (GND), U6.3 (GND), U6.9 (GND), U6.15 (GND), U6.27 (GND), U6.33 (GND), U6.39 (GND), U6.45 (GND), U6.51 (GND), U6.57 (GND), U6.71 (GND), U6.73 (GND), U6.P$1 (GND), U6.P$2 (GND); also elsewhere on the board
MFG1$6: U6.56 (MFG1)
MFG2$6: U6.58 (MFG2)
SUSCLK_32KHZ$6: Q5.3 (FO), U6.68 (SUSCLK)

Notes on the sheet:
M.2 Key M Connector

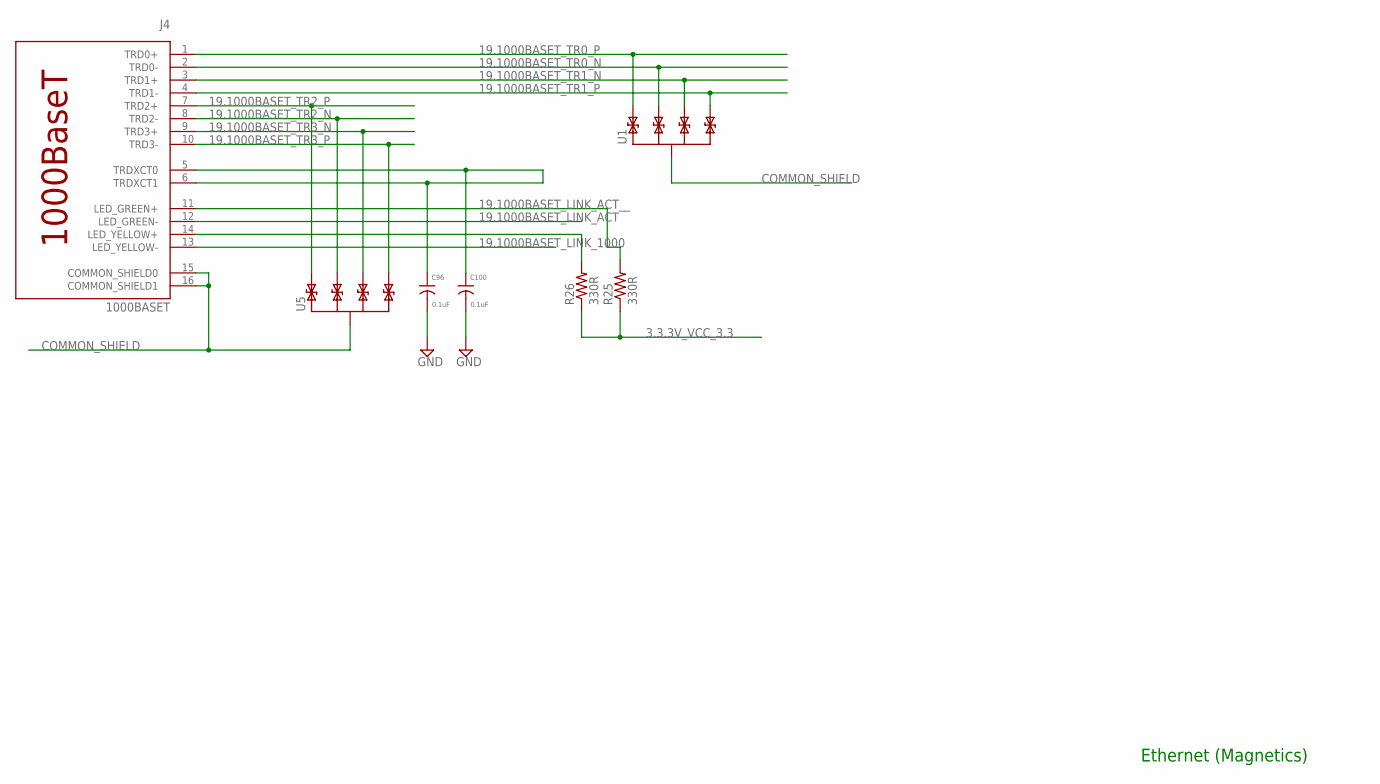
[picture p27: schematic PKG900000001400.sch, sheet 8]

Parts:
C96, C100: 0.1uF; 0201
J4: 1000BASET; 7499111447
R25, R26: 330R; 0201
U1, U5: TPD4E02B0410-USON; UFDFN-10

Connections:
3.3.3V_VCC_3.3: R25.1, R26.1; also elsewhere on the board
19.1000BASET_LINK_1000: J4.13 (LED_YELLOW-); also elsewhere on the board
19.1000BASET_LINK_ACT: J4.12 (LED_GREEN-); also elsewhere on the board
19.1000BASET_LINK_ACT__: J4.11 (LED_GREEN+), R25.2
19.1000BASET_TR0_N: J4.2 (TRD0-), U1.2, U1.9 (P2); also elsewhere on the board
19.1000BASET_TR0_P: J4.1 (TRD0+), U1.1, U1.10 (P1); also elsewhere on the board
19.1000BASET_TR1_N: J4.3 (TRD1+), U1.4 (P3), U1.7 (P3); also elsewhere on the board
19.1000BASET_TR1_P: J4.4 (TRD1-), U1.5 (P4), U1.6 (P4); also elsewhere on the board
19.1000BASET_TR2_N: J4.8 (TRD2-), U5.2, U5.9 (P2); also elsewhere on the board
19.1000BASET_TR2_P: J4.7 (TRD2+), U5.1, U5.10 (P1); also elsewhere on the board
19.1000BASET_TR3_N: J4.9 (TRD3+), U5.4 (P3), U5.7 (P3); also elsewhere on the board
19.1000BASET_TR3_P: J4.10 (TRD3-), U5.5 (P4), U5.6 (P4); also elsewhere on the board
COMMON_SHIELD: J4.15 (COMMON_SHIELD0), J4.16 (COMMON_SHIELD1), U1.3 (SHIELD), U1.8 (SHIELD), U5.3 (SHIELD), U5.8 (SHIELD); also elsewhere on the board
CT0$7: C96.1, C100.1, J4.5 (TRDXCT0), J4.6 (TRDXCT1)
GND: C96.2, C100.2; also elsewhere on the board
LED_YELLOW_P$7: J4.14 (LED_YELLOW+), R26.2

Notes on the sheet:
Ethernet (Magnetics)

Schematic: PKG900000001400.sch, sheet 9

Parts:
C97: 47pF; 0201
D8: B72590D50A060; D0402
R50: 10K 1%; 0201
R51: 150R; 0201
S2: EVQ

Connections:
19.NRESET_NRESET: C97.1, R51.2; also elsewhere on the board
19.VLOGIC_VLOGIC: R50.2; also elsewhere on the board
BTN_A$12: D8.P2, R50.1, R51.1, S2.B@2 (B')
GND: C97.2, D8.P1, S2.A@1 (A); also elsewhere on the board

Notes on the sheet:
Pushbutton

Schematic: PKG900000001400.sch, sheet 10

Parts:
C98: 47pF; 0201
D9: B72590D50A060; D0402
R30: 10K 1%; 0201
R31: 150R; 0201
S3: EVQ

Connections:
19.GPIO24_GPIO: C98.1, R31.2; also elsewhere on the board
19.VLOGIC_VLOGIC: R30.2; also elsewhere on the board
BTN_A$13: D9.P2, R30.1, R31.1, S3.B@2 (B')
GND: C98.2, D9.P1, S3.A@1 (A); also elsewhere on the board

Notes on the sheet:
Pushbutton

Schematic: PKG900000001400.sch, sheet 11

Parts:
D10: RED; D0603
Q6: BSS138; SOT23
R32: 1K; 0201
R33: 300R; 0402
R34: 100K 1%; 0201

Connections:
3.3.3V_VCC_3.3: R33.2; also elsewhere on the board
19.GPIO23_GPIO: R32.1, R34.2; also elsewhere on the board
ANODE$14: D10.A, R33.1
GATE$14: Q6.1 (G), R32.2
GND: Q6.2 (S), R34.1; also elsewhere on the board
LED-$14: D10.C, Q6.3 (D)

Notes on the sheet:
LED

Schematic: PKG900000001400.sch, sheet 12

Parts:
D15: GREEN; D0603
Q4: BSS138; SOT23
R35: 300R; 0402
R36: 100K 1%; 0201
R46: 1K; 0201

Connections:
3.3.3V_VCC_3.3: R35.2; also elsewhere on the board
19.SYS_EN_SYSEN: R36.2, R46.1; also elsewhere on the board
ANODE$15: D15.A, R35.1
GATE$15: Q4.1 (G), R46.2
GND: Q4.2 (S), R36.1; also elsewhere on the board
LED-$15: D15.C, Q4.3 (D)

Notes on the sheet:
LED

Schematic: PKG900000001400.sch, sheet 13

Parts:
C99: 4.7uF; 0603
D5, D18: B72590D50A060; D0402
D16, D17: PS04LTVA1; D0402
J5: USB_MICRO_B
L5: DLP11SN900HL2; 0504-DLP11S
R37: 0R; 0201

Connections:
21.USB2_D_N: L5.2; also elsewhere on the board
21.USB2_D_P: L5.3; also elsewhere on the board
21.USB2_VBUS: R37.1; also elsewhere on the board
COMMON_SHIELD: D5.P1, D16.P1, D17.P1, D18.P1, J5.COMMON_SHEILD1 (COMMON_SHIELD1), J5.COMMON_SHEILD2 (COMMON_SHIELD2), J5.COMMON_SHEILD3 (COMMON_SHIELD3), J5.COMMON_SHEILD4 (COMMON_SHIELD4), J5.COMMON_SHEILD5 (COMMON_SHIELD5), J5.COMMON_SHEILD6 (COMMON_SHIELD6); also elsewhere on the board
D_N$16: D17.P2, J5.P2 (D-), L5.1
D_P$16: D16.P2, J5.P3 (D+), L5.4
GND: C99.2, D5.P2, J5.P5 (GND); also elsewhere on the board
ID$16: J5.P4 (ID)
V5.0$16: C99.1, D18.P2, J5.P1 (VBUS), R37.2

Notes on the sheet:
Micro-B Jack

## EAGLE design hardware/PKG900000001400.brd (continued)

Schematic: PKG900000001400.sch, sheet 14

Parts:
C5, C15, C105, C106, C108: 0.1uF; 0201
C107, C109: 0.01uF; 0201
L2, L3, L4, L9: DLP11SN900HL2; 0504-DLP11S
R38: 75R; 0402
RP3: DNP; 741X08
U3: HDMI; 47151-001
U8: TPD13S523TSSOP; TSSOP16
U$29: TXS0104E; S-PVQFN-N14

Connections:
2.5.0V_VCC_5.0: C5.1, C108.1, U8.5 (5V_SUPPLY), U$29.14 (VCCB); also elsewhere on the board
19.HDMI0_CEC: RP3.4, U$29.2 (A1); also elsewhere on the board
19.HDMI0_CLOCK_N: L4.2, U8.9 (D3-); also elsewhere on the board
19.HDMI0_CLOCK_P: L4.3, U8.10 (D3+); also elsewhere on the board
19.HDMI0_D0_N: L3.2, U8.11 (D2-); also elsewhere on the board
19.HDMI0_D0_P: L3.3, U8.12 (D2+); also elsewhere on the board
19.HDMI0_D1_N: L2.2, U8.13 (D1-); also elsewhere on the board
19.HDMI0_D1_P: L2.3, U8.14 (D1+); also elsewhere on the board
19.HDMI0_D2_N: L9.2, U8.15 (D0-); also elsewhere on the board
19.HDMI0_D2_P: L9.3, U8.16 (D0+); also elsewhere on the board
19.HDMI0_DDC_SCL: RP3.3, U$29.3 (A2); also elsewhere on the board
19.HDMI0_DDC_SDA: RP3.2, U$29.4 (A3); also elsewhere on the board
19.HDMI0_HPD: RP3.1, U$29.5 (A4); also elsewhere on the board
19.VLOGIC_VLOGIC: C15.1, C106.1, C107.1, C109.1, U$29.1 (VCCA), U$29.8 (OE); also elsewhere on the board
CEC$17: RP3.5, U3.13, U8.1 (CTRL1), U$29.13 (B1)
COMMON_SHIELD: U3.G1 (20), U3.G2 (21), U3.G3 (22), U3.G4 (23); also elsewhere on the board
CON_5V0$17: C105.1, U3.18, U8.6 (5V_OUT)
DDC_SCL$17: RP3.6, U3.15, U8.2 (CTRL2), U$29.12 (B2)
DDC_SDA$17: RP3.7, U3.16, U8.3 (CTRL3), U$29.11 (B3)
GND: C5.2, C15.2, C105.2, C106.2, C107.2, C108.2, C109.2, R38.1, U3.2, U3.5, U3.8, U3.11, U3.17, U8.8 (GND), U$29.7 (GND); also elsewhere on the board
HPD$17: RP3.8, U3.19, U8.4 (CTRL4), U$29.10 (B4)
TXD0_CONN_N$17: L3.1, U3.9
TXD0_CONN_P$17: L3.4, U3.7
TXD1_CONN_N$17: L2.1, U3.6
TXD1_CONN_P$17: L2.4, U3.4
TXD2_CONN_N$17: L9.1, U3.3
TXD2_CONN_P$17: L9.4, U3.1
TXDC_CONN_N$17: L4.1, U3.12
TXDC_CONN_P$17: L4.4, U3.10
UTIL$17: R38.2, U3.14, U8.7 (CTRL5)

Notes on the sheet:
HDMI
PWR<->GND via stitching around bottom side signals (per Toradex layout guidelines)
TPD13S523 sheet says to GND unused pins with 75ohm resistor.

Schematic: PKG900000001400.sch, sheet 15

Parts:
C110: 0.1uF; 0201
R13, R44: 10K 1%; 0201
RP1, RP2: DNP; RP741X083
U2: TS3A5223; UQFN-10

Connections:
1.USB_DEVICE_VBUS: R13.2; also elsewhere on the board
18.UART1_RXD: RP1.1, U2.7 (NC2); also elsewhere on the board
18.UART1_TXD: RP1.2, U2.5 (NC1); also elsewhere on the board
18.UART2_RXD: RP2.4, U2.10 (NO2); also elsewhere on the board
18.UART2_TXD: RP2.3, U2.2 (NO1); also elsewhere on the board
19.UART0_RXD: RP1.8, RP2.5, U2.9 (COM2); also elsewhere on the board
19.UART0_TXD: RP1.7, RP2.6, U2.3 (COM1); also elsewhere on the board
19.VLOGIC_VLOGIC: C110.1, U2.1 (VCC); also elsewhere on the board
GND: C110.2, R44.1, U2.6 (GND); also elsewhere on the board
UART_SEL$: R13.1, R44.2, U2.4 (SEL1), U2.8 (SEL2)

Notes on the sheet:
Quad 2 Input MUX

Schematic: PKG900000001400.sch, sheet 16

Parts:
J2, J7: DF40C-100DS-0.4V(51); HRS_DF40C-100DS-0.4V(51)
MP1, MP2, MP3, MP4: 9774015151R; WA-SMSI_9774___151
Q1: BSS138; SOT23
Q2, Q3: FDN360P; SOT23
R1, R3: 0R; 0201
R2: DNP; 0201
R5: 10K 1%; 0201

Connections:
1.8V_OUT$19: J7.88, J7.90, R2.1
2.5.0V_VCC_5.0: J7.77, J7.79, J7.81, J7.83, J7.85, J7.87; also elsewhere on the board
3.3V_OUT$19: J7.84, J7.86, Q2.3 (D), R1.1
19.3.3V_VCC_3.3: Q3.3 (D), R3.2
19.1000BASET_LINK_100: J7.19
19.1000BASET_LINK_1000: J7.17; also elsewhere on the board
19.1000BASET_LINK_ACT: J7.15; also elsewhere on the board
19.1000BASET_TR0_N: J7.10; also elsewhere on the board
19.1000BASET_TR0_P: J7.12; also elsewhere on the board
19.1000BASET_TR1_N: J7.6; also elsewhere on the board
19.1000BASET_TR1_P: J7.4; also elsewhere on the board
19.1000BASET_TR2_N: J7.9; also elsewhere on the board
19.1000BASET_TR2_P: J7.11; also elsewhere on the board
19.1000BASET_TR3_N: J7.5; also elsewhere on the board
19.1000BASET_TR3_P: J7.3; also elsewhere on the board
19.CAM0_C_N: J2.40; also elsewhere on the board
19.CAM0_C_P: J2.42; also elsewhere on the board
19.CAM0_D1_N: J2.28; also elsewhere on the board
19.CAM0_D1_P: J2.30; also elsewhere on the board
19.CAM0_D2_N: J2.34; also elsewhere on the board
19.CAM0_D2_P: J2.36; also elsewhere on the board
19.CAM1_C_N: J2.27; also elsewhere on the board
19.CAM1_C_P: J2.29; also elsewhere on the board
19.CAM1_D1_N: J2.15; also elsewhere on the board
19.CAM1_D1_P: J2.17; also elsewhere on the board
19.CAM1_D2_N: J2.21; also elsewhere on the board
19.CAM1_D2_P: J2.23; also elsewhere on the board
19.CAM1_D3_N: J2.33
19.CAM1_D3_P: J2.35
19.CAM1_D4_N: J2.39
19.CAM1_D4_P: J2.41
19.DSI1_C_N: J2.87; also elsewhere on the board
19.DSI1_C_P: J2.89; also elsewhere on the board
19.DSI1_D1_N: J2.75; also elsewhere on the board
19.DSI1_D1_P: J2.77; also elsewhere on the board
19.DSI1_D2_N: J2.81; also elsewhere on the board
19.DSI1_D2_P: J2.83; also elsewhere on the board
19.DSI1_D3_N: J2.93
19.DSI1_D3_P: J2.95
19.DSI1_D4_N: J2.94
19.DSI1_D4_P: J2.96
19.GPIO2_GPIO: J7.58; also elsewhere on the board
19.GPIO3_GPIO: J7.56; also elsewhere on the board
19.GPIO4_GPIO: J7.54; also elsewhere on the board
19.GPIO5_GPIO: J7.34; also elsewhere on the board
19.GPIO6_GPIO: J7.30; also elsewhere on the board
19.GPIO7_GPIO: J7.37; also elsewhere on the board
19.GPIO8_GPIO: J7.39; also elsewhere on the board
19.GPIO9_GPIO: J7.40; also elsewhere on the board
19.GPIO10_GPIO: J7.44; also elsewhere on the board
19.GPIO11_GPIO: J7.38; also elsewhere on the board
19.GPIO12_GPIO: J7.31; also elsewhere on the board
19.GPIO13_GPIO: J7.28; also elsewhere on the board
19.GPIO16_GPIO: J7.29; also elsewhere on the board
19.GPIO17_GPIO: J7.50; also elsewhere on the board
19.GPIO18_GPIO: J7.49; also elsewhere on the board
19.GPIO19_GPIO: J7.26; also elsewhere on the board
19.GPIO20_GPIO: J7.27; also elsewhere on the board
19.GPIO21_GPIO: J7.25; also elsewhere on the board
19.GPIO22_GPIO: J7.46; also elsewhere on the board
19.GPIO23_GPIO: J7.47; also elsewhere on the board
19.GPIO24_GPIO: J7.45; also elsewhere on the board
19.GPIO25_GPIO: J7.41; also elsewhere on the board
19.GPIO26_GPIO: J7.24; also elsewhere on the board
19.GPIO27_GPIO: J7.48; also elsewhere on the board
19.GPIO_CAMERA_GPIO: J7.97; also elsewhere on the board
19.HDMI0_CEC: J2.51; also elsewhere on the board
19.HDMI0_CLOCK_N: J2.90; also elsewhere on the board
19.HDMI0_CLOCK_P: J2.88; also elsewhere on the board
19.HDMI0_D0_N: J2.84; also elsewhere on the board
19.HDMI0_D0_P: J2.82; also elsewhere on the board
19.HDMI0_D1_N: J2.78; also elsewhere on the board
19.HDMI0_D1_P: J2.76; also elsewhere on the board
19.HDMI0_D2_N: J2.72; also elsewhere on the board
19.HDMI0_D2_P: J2.70; also elsewhere on the board
19.HDMI0_DDC_SCL: J2.100; also elsewhere on the board
19.HDMI0_DDC_SDA: J2.99; also elsewhere on the board
19.HDMI0_HPD: J2.53; also elsewhere on the board
19.I2C_ID_SCL: J7.35; also elsewhere on the board
19.I2C_ID_SDA: J7.36; also elsewhere on the board
19.I2C_SCL: J7.80; also elsewhere on the board
19.I2C_SDA: J7.82; also elsewhere on the board
19.NRESET_NRESET: J7.92; also elsewhere on the board
19.PCIE_CLKREQ_GPIO: J2.2; also elsewhere on the board
19.PCIE_CLK_N: J2.12; also elsewhere on the board
19.PCIE_CLK_P: J2.10; also elsewhere on the board
19.PCIE_RST_GPIO: J2.9; also elsewhere on the board
19.PCIE_RX0_N: J2.18; also elsewhere on the board
19.PCIE_RX0_P: J2.16; also elsewhere on the board
19.PCIE_TX0_N: J2.24; also elsewhere on the board
19.PCIE_TX0_P: J2.22; also elsewhere on the board
19.SYS_EN_SYSEN: J7.100, Q1.1 (G), R5.2; also elsewhere on the board
19.UART0_RXD: J7.51; also elsewhere on the board
19.UART0_TXD: J7.55; also elsewhere on the board
19.USB3_CC1_GPIO: J7.94
19.USB3_CC2_GPIO: J7.96
19.USB_HOST_D_N: J2.3; also elsewhere on the board
19.USB_HOST_D_P: J2.5; also elsewhere on the board
19.VLOGIC_VLOGIC: R3.1; also elsewhere on the board
!RPIBOOT$19: J7.93; also elsewhere on the board
DS_LOAD$19: Q2.2 (S), Q3.2 (S)
EEPROM_!WP: J7.20
ETH_SYNC_IN: J7.16
ETH_SYNC_OUT: J7.18
GLOBAL_EN: J7.99
GND: J2.7, J2.8, J2.13, J2.14, J2.19, J2.20, J2.25, J2.26, J2.31, J2.32, J2.37, J2.38, J2.44, J2.50, J2.55, J2.56, J2.61, J2.62, J2.67, J2.68, J2.73, J2.74, J2.79, J2.80, J2.85, J2.86, J2.91, J2.92, J2.97, J2.98, J7.1, J7.2, J7.7, J7.8, J7.13, J7.14, J7.22, J7.23, J7.32, J7.33, J7.42, J7.43, J7.52, J7.53, J7.59, J7.60, J7.65, J7.66, J7.71, J7.74, J7.98, MP1.1, MP2.1, MP3.1, MP4.1, Q1.2 (S), R5.1; also elsewhere on the board
GPIO_VREF$19: J7.78, R1.2, R2.2; also elsewhere on the board
LOAD_GATE$19: Q1.3 (D), Q2.1 (G), Q3.1 (G)
PI_!LED_ACT: J7.21
PI_LED_!PWR: J7.95
SD_PWR_ON: J7.75
SD_VDD_OV: J7.73
VDAC_COMP: J2.11

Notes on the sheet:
Raspberry Pi CM4
GPIO
High Speed

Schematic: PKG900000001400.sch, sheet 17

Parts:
C6: 0.1uF; 0201
IC6: CAT24C256YI-G; TSSOP8
R6, R7, R8: 100K 1%; 0201
R9, R10: 1K5; 0201
R11: 10K 1%; 0201
S1: EVQ; KMT0

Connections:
19.I2C_ID_SCL: IC6.6 (SCL), R10.1; also elsewhere on the board
19.I2C_ID_SDA: IC6.5 (SDA), R9.1; also elsewhere on the board
!RPIBOOT$19: S1.3 (B), S1.4 (B'); also elsewhere on the board
A0$19: IC6.1 (A0), R8.2
A1$19: IC6.2 (A1), R7.2
A2$19: IC6.3 (A2), R6.2
GND: C6.2, IC6.4 (GND), IC6.7 (WP), R6.1, R7.1, R11.1; also elsewhere on the board
GPIO_VREF$19: C6.1, IC6.8 (VCC), R8.1, R9.2, R10.2; also elsewhere on the board
RPIBOOT_SWITCH$19: R11.2, S1.1 (A), S1.2 (A')

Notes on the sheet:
Raspberry Pi CM4

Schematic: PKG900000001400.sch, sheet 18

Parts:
C2: 220uF/6.3V; 1206
C3: DNP; 1206
C4: 0.1uF; 0201
D1, D2: PS04LTVA1; D0402
D3, D4: B72590D50A060; D0402
FB1, FB2: 120R 1A; 0402
IC1: TPS2051; MSOP8-PAD
J8: USB-A-S
L1: DLP11SN900HL2; 0504-DLP11S

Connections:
2.5.0V_VCC_5.0: C4.1, IC1.2 (IN), IC1.3 (IN); also elsewhere on the board
3.3.3V_VCC_3.3: IC1.4 (EN); also elsewhere on the board
21.USB1_D_N: L1.2; also elsewhere on the board
21.USB1_D_P: L1.3; also elsewhere on the board
21.USB1_NOC: IC1.5 (NOC)
21.USB1_VBUS: FB1.1, IC1.6 (OUT), IC1.7 (OUT), IC1.8 (OUT)
COMMON_SHIELD: D1.P1, D2.P1, D3.P1, D4.P1, J8.P$5 (P1), J8.P$6 (P2); also elsewhere on the board
GND: C2.2, C3.2, C4.2, FB2.1, IC1.1 (GND), IC1.TP (GND); also elsewhere on the board
USBH_GND$20: D3.P2, FB2.2, J8.GND
USBH_N$20: D2.P2, J8.D-, L1.1
USBH_P$20: D1.P2, J8.D+ (VBUS), L1.4
USBH_VBUSF$20: C2.1, C3.1, D4.P2, FB1.2, J8.VBUS (D+)

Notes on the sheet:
USB HOST

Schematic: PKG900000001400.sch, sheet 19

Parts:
C103: 0.1uF; 0201
R27, R28: 10K 1%; 0201
U26: TS3USB30; UQFN-10

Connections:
3.3.3V_VCC_3.3: C103.1, U26.9 (VCC); also elsewhere on the board
19.USB_HOST_D_N: U26.5 (D-); also elsewhere on the board
19.USB_HOST_D_P: U26.3 (D+); also elsewhere on the board
21.USB1_D_N: U26.7 (D1-); also elsewhere on the board
21.USB1_D_P: U26.1 (D1+); also elsewhere on the board
21.USB2_D_N: U26.6 (D2-); also elsewhere on the board
21.USB2_D_P: U26.2 (D2+); also elsewhere on the board
21.USB2_VBUS: R27.2, U26.10 (S); also elsewhere on the board
GND: C103.2, R27.1, R28.1, U26.4 (GND); also elsewhere on the board
USBMUX_OE$13: R28.2, U26.8 (!OE)

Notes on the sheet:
USB 2-Port Switch

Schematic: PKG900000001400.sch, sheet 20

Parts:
U4: MALE; 2X20

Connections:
2.5.0V_VCC_5.0: U4.2, U4.4; also elsewhere on the board
3.3.3V_VCC_3.3: U4.1, U4.17; also elsewhere on the board
18.UART1_RXD: U4.10; also elsewhere on the board
18.UART1_TXD: U4.8; also elsewhere on the board
19.GPIO2_GPIO: U4.3; also elsewhere on the board
19.GPIO3_GPIO: U4.5; also elsewhere on the board
19.GPIO4_GPIO: U4.7; also elsewhere on the board
19.GPIO5_GPIO: U4.29; also elsewhere on the board
19.GPIO6_GPIO: U4.31; also elsewhere on the board
19.GPIO7_GPIO: U4.26; also elsewhere on the board
19.GPIO8_GPIO: U4.24; also elsewhere on the board
19.GPIO9_GPIO: U4.21; also elsewhere on the board
19.GPIO10_GPIO: U4.19; also elsewhere on the board
19.GPIO11_GPIO: U4.23; also elsewhere on the board
19.GPIO12_GPIO: U4.32; also elsewhere on the board
19.GPIO13_GPIO: U4.33; also elsewhere on the board
19.GPIO16_GPIO: U4.36; also elsewhere on the board
19.GPIO17_GPIO: U4.11; also elsewhere on the board
19.GPIO18_GPIO: U4.12; also elsewhere on the board
19.GPIO19_GPIO: U4.35; also elsewhere on the board
19.GPIO20_GPIO: U4.38; also elsewhere on the board
19.GPIO21_GPIO: U4.40; also elsewhere on the board
19.GPIO22_GPIO: U4.15; also elsewhere on the board
19.GPIO23_GPIO: U4.16; also elsewhere on the board
19.GPIO24_GPIO: U4.18; also elsewhere on the board
19.GPIO25_GPIO: U4.22; also elsewhere on the board
19.GPIO26_GPIO: U4.37; also elsewhere on the board
19.GPIO27_GPIO: U4.13; also elsewhere on the board
GND: U4.6, U4.9, U4.14, U4.20, U4.25, U4.30, U4.34, U4.39; also elsewhere on the board
P27: U4.27
P28: U4.28

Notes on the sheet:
40-Pin Header

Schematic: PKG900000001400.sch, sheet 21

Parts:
J9: FPC-15VERT; 1-1734248-5

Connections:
3.3.3V_VCC_3.3: J9.1_15 (15); also elsewhere on the board
19.CAM1_C_N: J9.1_8 (8); also elsewhere on the board
19.CAM1_C_P: J9.1_9 (9); also elsewhere on the board
19.CAM1_D1_N: J9.1_2 (2); also elsewhere on the board
19.CAM1_D1_P: J9.1_3 (3); also elsewhere on the board
19.CAM1_D2_N: J9.1_5 (5); also elsewhere on the board
19.CAM1_D2_P: J9.1_6 (6); also elsewhere on the board
19.GPIO_CAMERA_GPIO: J9.1_11 (11); also elsewhere on the board
19.I2C_SCL: J9.1_13 (13); also elsewhere on the board
19.I2C_SDA: J9.1_14 (14); also elsewhere on the board
GND: J9.1_1 (1), J9.1_4 (4), J9.1_7 (7), J9.1_10 (10); also elsewhere on the board

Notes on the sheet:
RPi CSI Vertical Connector

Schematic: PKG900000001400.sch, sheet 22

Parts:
J10: FPC-15VERT; 1-1734248-5

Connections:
3.3.3V_VCC_3.3: J10.1_15 (15); also elsewhere on the board
19.CAM0_C_N: J10.1_8 (8); also elsewhere on the board
19.CAM0_C_P: J10.1_9 (9); also elsewhere on the board
19.CAM0_D1_N: J10.1_2 (2); also elsewhere on the board
19.CAM0_D1_P: J10.1_3 (3); also elsewhere on the board
19.CAM0_D2_N: J10.1_5 (5); also elsewhere on the board
19.CAM0_D2_P: J10.1_6 (6); also elsewhere on the board
19.GPIO_CAMERA_GPIO: J10.1_11 (11); also elsewhere on the board
19.I2C_ID_SCL: J10.1_13 (13); also elsewhere on the board
19.I2C_ID_SDA: J10.1_14 (14); also elsewhere on the board
GND: J10.1_1 (1), J10.1_4 (4), J10.1_7 (7), J10.1_10 (10); also elsewhere on the board

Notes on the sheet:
RPi CSI Vertical Connector

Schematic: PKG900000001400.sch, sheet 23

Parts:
J1: FPC-15VERT; 1-1734248-5

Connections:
3.3.3V_VCC_3.3: J1.1_14 (14), J1.1_15 (15); also elsewhere on the board
19.DSI1_C_N: J1.1_5 (5); also elsewhere on the board
19.DSI1_C_P: J1.1_6 (6); also elsewhere on the board
19.DSI1_D1_N: J1.1_8 (8); also elsewhere on the board
19.DSI1_D1_P: J1.1_9 (9); also elsewhere on the board
19.DSI1_D2_N: J1.1_2 (2); also elsewhere on the board
19.DSI1_D2_P: J1.1_3 (3); also elsewhere on the board
19.I2C_SCL: J1.1_11 (11); also elsewhere on the board
19.I2C_SDA: J1.1_12 (12); also elsewhere on the board
GND: J1.1_1 (1), J1.1_4 (4), J1.1_7 (7), J1.1_10 (10), J1.1_13 (13); also elsewhere on the board

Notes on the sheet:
DSI Vertical Connector

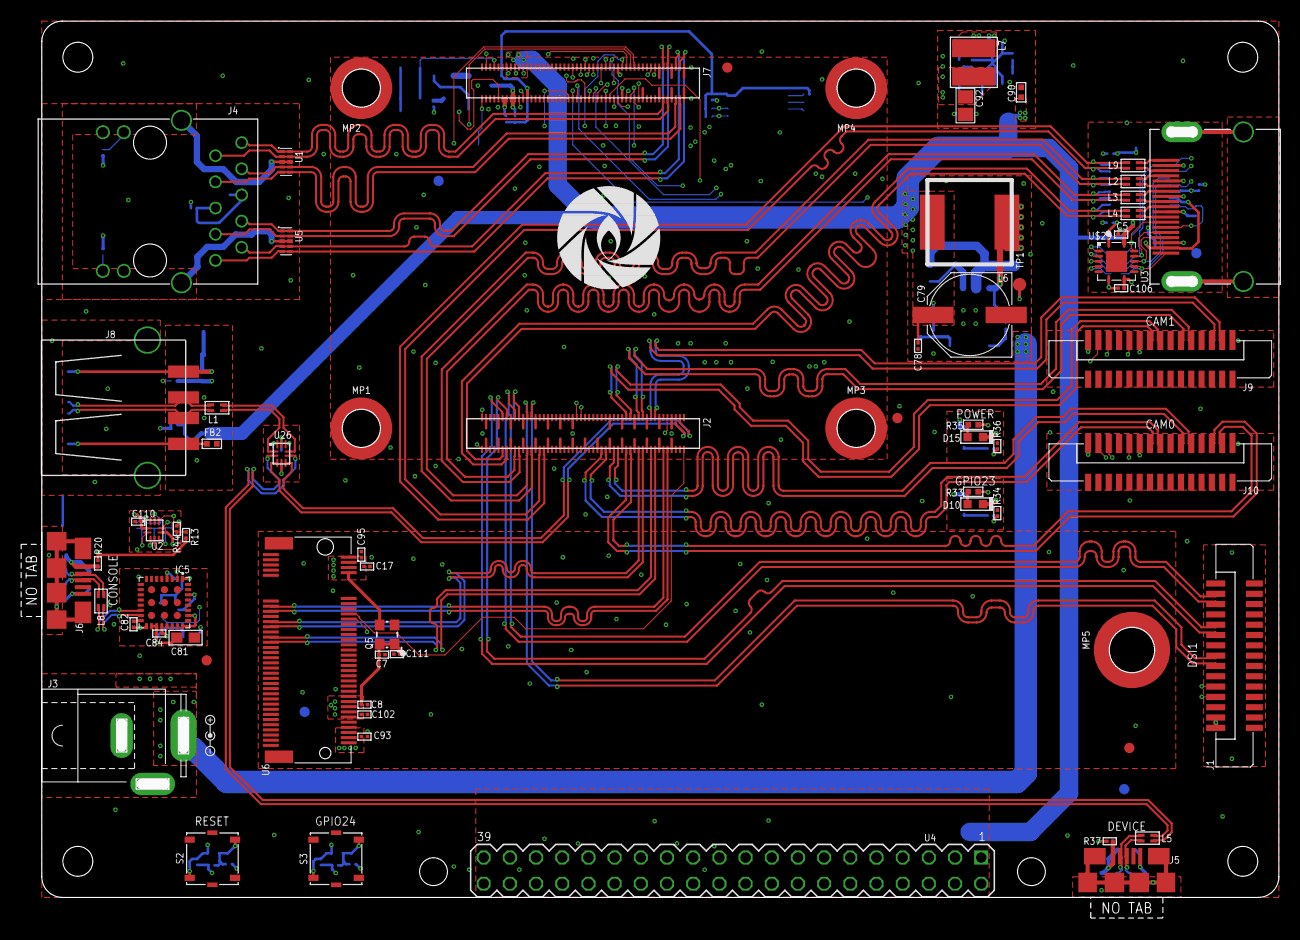
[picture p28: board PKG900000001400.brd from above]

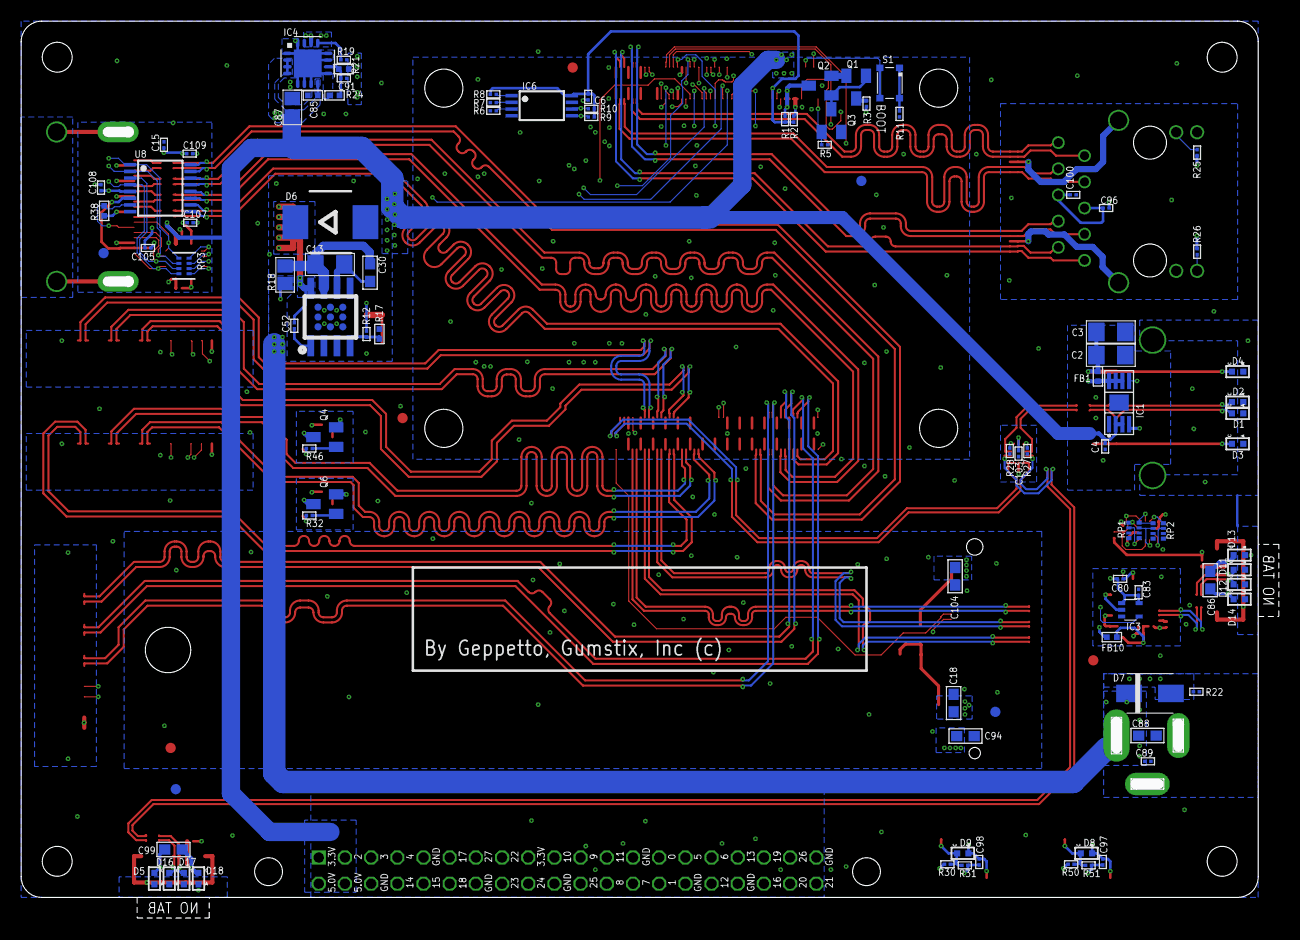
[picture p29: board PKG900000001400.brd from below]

Board: 6 copper layers, 122.0 x 87.0 mm, 170 parts (95 on the bottom side), 161 nets.

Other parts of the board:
U$14, U$16, U$18, U$20: DNP; GEPPETTO_HOLE_2.9

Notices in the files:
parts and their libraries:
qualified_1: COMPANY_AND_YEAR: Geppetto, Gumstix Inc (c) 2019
